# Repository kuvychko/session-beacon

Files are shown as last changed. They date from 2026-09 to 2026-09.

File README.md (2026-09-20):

# Session Beacon

A small USB-attached status light for Claude Code. It shows, at a glance, every Claude Code session running on the machine, which ones are waiting on you, and a few coarse usage numbers, on a 1.8" colour TFT sitting next to the monitor.

The problem it solves: with three or four VS Code windows each running Claude Code, it is easy to leave one session blocked on a permission prompt for twenty minutes without noticing. Desktop notifications get lost or dismissed. A dedicated physical display does not.

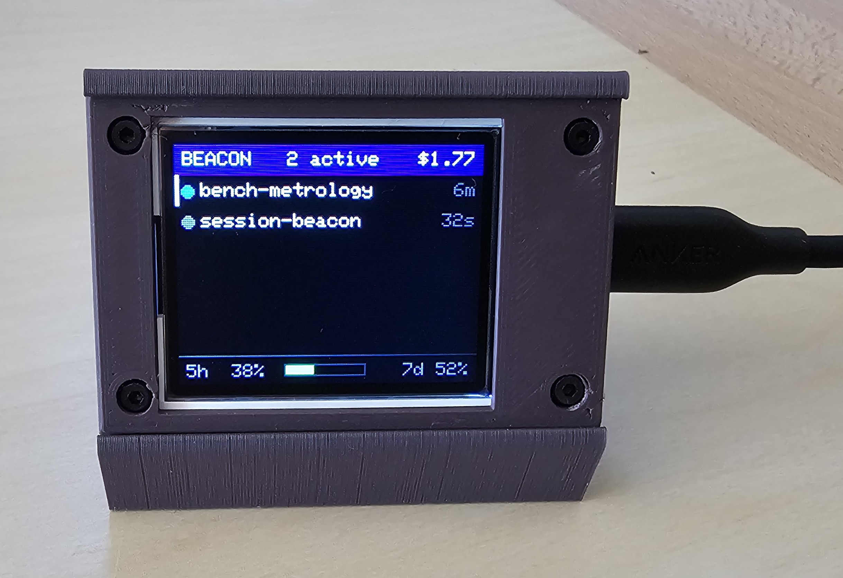
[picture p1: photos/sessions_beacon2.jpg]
The finished beacon


Two sessions on screen, in the 25-degree desk stand. `bench-metrology` last changed
state six minutes ago, `session-beacon` thirty-two seconds ago. The bar down the left
of the top row marks the session the footer is describing. The header totals spend
across every live session; the footer is caught on its usage page, showing 38% of the
rolling five-hour limit and 52% of the seven-day one.

---

## Hardware

| Part | Notes |
|---|---|
| Arduino Nano ESP32, **headerless** | ABX00092, not the headered ABX00083. ESP32-S3, native USB CDC, 3.3 V logic. The reference build, complete and in daily use |
| *or* Waveshare RP2040-Zero, **without headers** | The cheaper, smaller build, since Wi-Fi is never used. Runs the same firmware from the same source, on the same daemon |
| 1.8" TFT, 128x160, ST7735S | SPI, 3.3 V, 8-pin header, [this JESSINIE listing](https://www.amazon.com/dp/B0D31BGJWF). Both panels bought from it were BGR-wired and need a one-line colour-order fix, without which red and blue render swapped. Verify yours; the check is free. |
| USB-C cable | Data + power, nothing else needed |
| Enclosure, 3 printed parts | 40 x 60 mm, 19 mm deep. The middle and back parts come in a version for each board. SolidWorks, STEP and 3MF in [`enclosure/`](enclosure) |
| Desk stand, 1 printed part, optional | Tilts the screen back 25 degrees. The case is a friction fit in the slot, so nothing fastens it |
| 4x M2 x 16 socket-head screws + 4x M2 nuts | Head and nut both counter-sunk into the 19 mm stack. Length excludes the head, per the machine screw convention |
| 26 AWG silicone hookup wire, tinned copper | Eight conductors, soldered direct to the display's bent-over header. Silicone is required, not preferred: PVC is stiff enough to lift the board out of its retaining ridges |

Wiring needs no passives or level shifting: eight conductors, all 3.3 V. The Nano's
is carried over from the `env_monitoring` firmware. See
[docs/hardware.md](docs/hardware.md) for the pinout and bring-up procedure, and
[docs/enclosure.md](docs/enclosure.md) for the case and the full bill of materials.

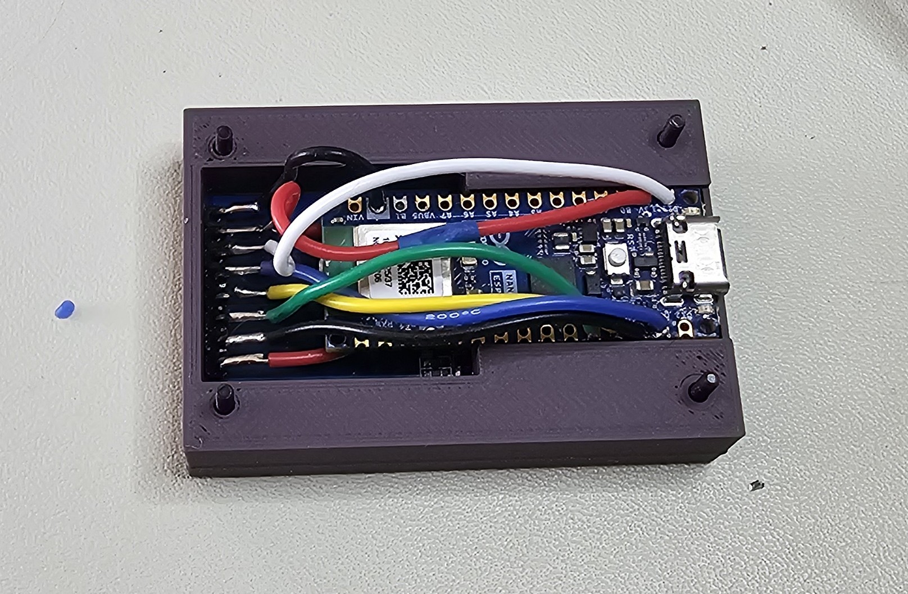
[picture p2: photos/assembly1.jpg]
Inside the case


The open case shows why three items in that list are requirements rather than
preferences. The Arduino is the headerless board, so its pads are bare and the printed
ridges can close directly onto the PCB to retain it. The display's eight-pin header is
bent flat against the board with wires soldered straight to it, because a socket would
not fit under the lid. And the wire is silicone: one jacket is printed `200 C`, which is
the rating that stops it shrinking back from the iron on leads this short.

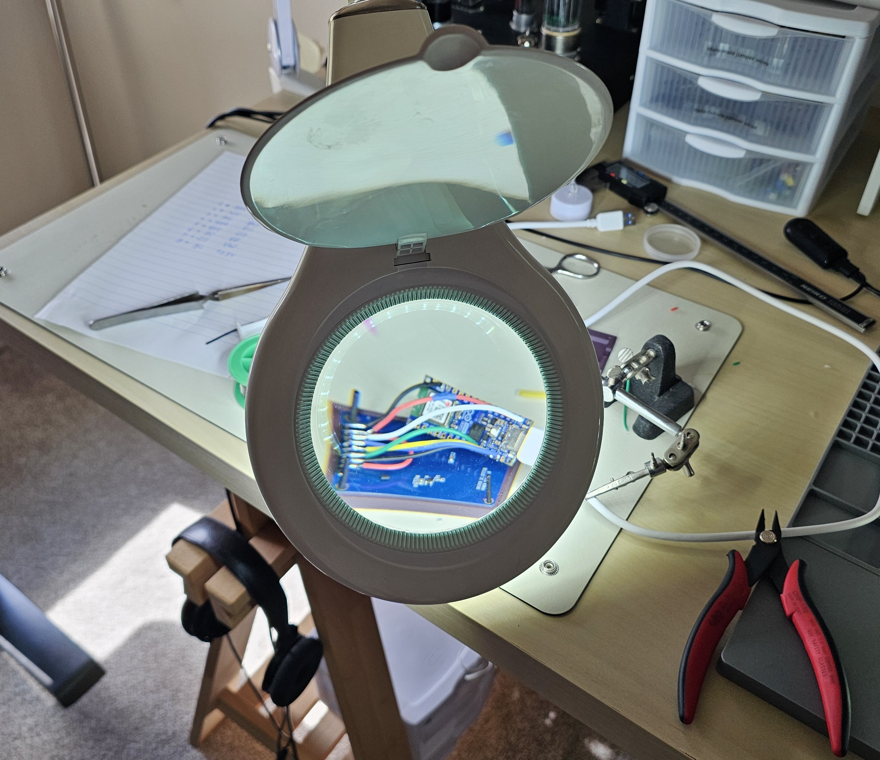
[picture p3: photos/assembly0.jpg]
Soldering under a magnifier


Soldering the bent header. Eight joints on 2.54 mm pitch, done under a magnifier lamp.

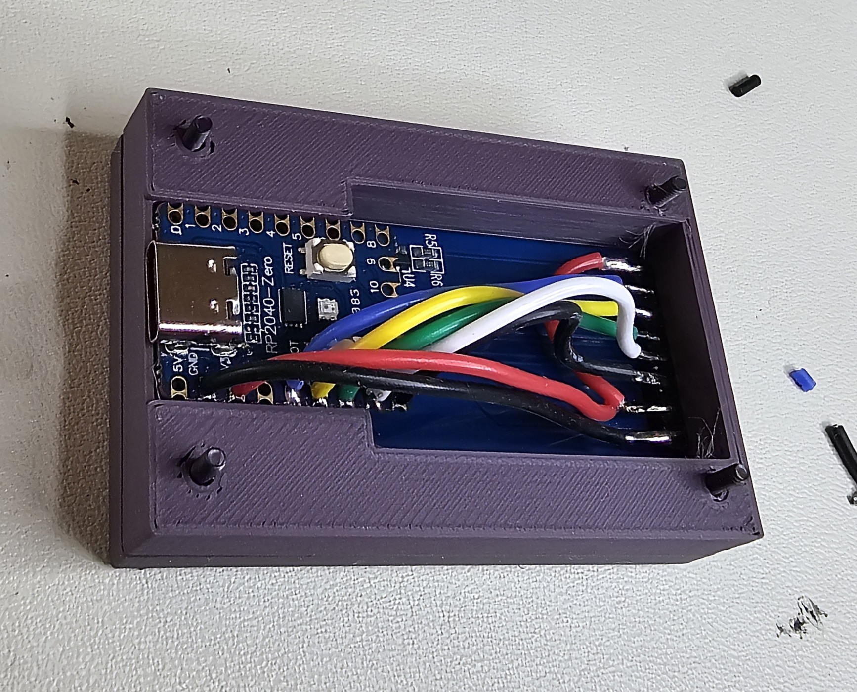
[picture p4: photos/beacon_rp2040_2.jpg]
The RP2040-Zero build, wired and seated in its case


The second build, on a Waveshare RP2040-Zero. Same display, same eight wires, same
firmware from the same source; a different mid and back part hold the smaller board.
Its parts laid out before assembly, and what differs between the two builds, are in
[docs/enclosure.md](docs/enclosure.md#two-builds).

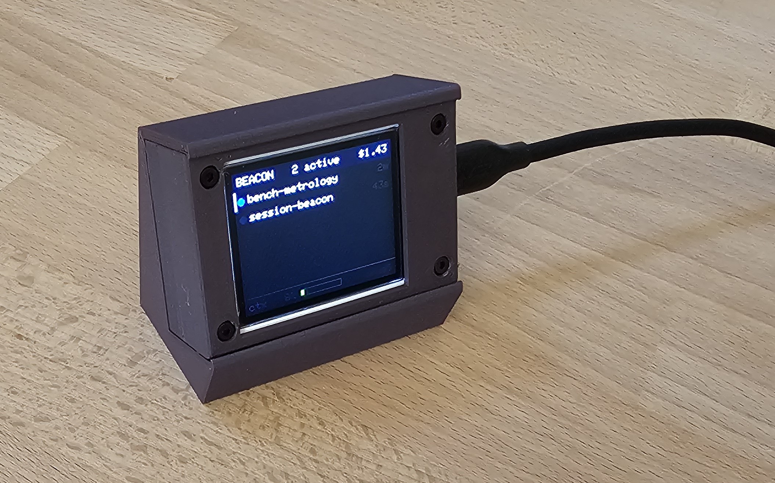
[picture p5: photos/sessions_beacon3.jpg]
The beacon in its stand, from the side


The stand seen from off-axis. Flat on the desk the screen points at the ceiling; 25
degrees back is what makes it readable from a seated position. The case is a friction
fit in the slot, so the stand is genuinely optional and nothing about the case depends
on it.

---

## How it works

```mermaid
flowchart LR
    subgraph pc["Windows PC"]
        cc1["Claude Code\n(VS Code #1)"]
        cc2["Claude Code\n(VS Code #2)"]
        cc3["Claude Code\n(terminal)"]
        hook["curl\n(one call per hook event)"]
        daemon["beacon-host\n(Python daemon)"]
        cc1 & cc2 & cc3 -->|"hooks + statusline"| hook
        hook -->|"HTTP POST\nlocalhost:47391"| daemon
    end
    subgraph dev["Nano ESP32"]
        fw["firmware"]
        tft["ST7735 TFT"]
        fw --> tft
    end
    daemon -->|"USB serial\nnewline JSON"| fw
```

1. **Claude Code hooks** fire on session lifecycle events. Each one is a single `curl` call to the daemon, which measured about eight times cheaper than starting a Python interpreter per event.
2. **beacon-host** keeps a per-session state machine (see [what the colours mean](#what-the-colours-mean)), decides how loudly each one should be shown, enriches it with cost and context data from the statusline hook, and pushes a compact snapshot to the device whenever anything changes.
3. **Firmware** is deliberately dumb: it parses the snapshot and draws it. All policy lives on the host so it can change without reflashing.

On the screen, one row per session:

```
+----------------------------------------+
| BEACON      6 active         $61.17    |
|----------------------------------------|
|############ env_monitoring     44s ####|  wants you now: filled red, pulsing
|############ data-pipeline       5m ####|  still waiting: filled red, static
| o session-beacon                 2m    |  blue: working
| o inventory..vice2               3m    |  cyan: idle, background work running
| o web-frontend                  15m    |  amber: busy but gone quiet
| o homelab                        7s    |  green: finished its turn
|----------------------------------------|
| ctx  73% [#######...]         opus5    |  <- 4s
| 5h   92% [#########.]      7d  28%     |  -> 4s
+----------------------------------------+
```

The bar down the far left of the top row marks the session the footer's context
page is describing. The footer alternates every four seconds between that session
and your account's rolling five-hour and seven-day usage.

State is carried by colour rather than a word, and the elapsed time is how long a
session has been in that state. The one that wants you fills its whole row and
pulses, which reads from across a desk in a way six-pixel text does not.

**The alarm decays.** It pulses for two minutes, then holds a static red for
another eight, then settles to an amber dot and sinks below the working sessions.
Leaving a session parked is a normal way to work, and a red light that never goes
out is one you stop reading. Both timings are config. See
[the attention ladder](docs/architecture.md#the-attention-ladder).

Labels longer than the 16 characters a row has room for lose their middle, not
their end, so `inventory-service2` shows as `inventory..vice2`. Two clones of one
repository usually differ only at the end of the name.

### What the colours mean

Every row is in one of these states. The diagram shows how a session moves
between them. All the timings are defaults and can be changed in
`host/config.toml`.

```mermaid
stateDiagram-v2
    direction LR
    state "STARTING: grey dot" as STARTING
    state "WORKING: blue dot" as WORKING
    state "IDLE: green dot" as IDLE
    state "NEEDS_LOOK: cyan dot and age" as NEEDS_LOOK
    state "STALE: amber dot and age" as STALE
    state "ERROR: magenta dot and age" as ERROR
    state "Waiting on you" as ASK {
        state "NEEDS_INPUT: red row, pulsing" as NEEDS_INPUT
        state "NEEDS_HELD: red row, steady" as NEEDS_HELD
        state "WAITING: amber dot and age" as WAITING
        [*] --> NEEDS_INPUT
        NEEDS_INPUT --> NEEDS_HELD: 2 min in
        NEEDS_HELD --> WAITING: 10 min in
    }

    [*] --> STARTING: session opens
    STARTING --> WORKING: you send a prompt
    IDLE --> WORKING: you send a prompt
    ERROR --> WORKING: you send a prompt
    WORKING --> IDLE: Claude finishes its turn
    WORKING --> ERROR: API error, e.g. a rate limit
    WORKING --> STALE: no activity for 5 min
    IDLE --> STALE: no word from Claude Code for 10 min
    STARTING --> STALE: same
    STALE --> WORKING: activity resumes
    WORKING --> ASK: permission prompt or question
    IDLE --> ASK: Claude has waited on you a while
    IDLE --> NEEDS_LOOK: same, but a workflow or background shell is still running
    NEEDS_LOOK --> WORKING: Claude picks up again
    NEEDS_LOOK --> ASK: still quiet 5 min later
    ASK --> WORKING: you answer

    classDef grey fill:#8c8c8c,stroke:#5c5c5c,color:#fff
    classDef blue fill:#009eff,stroke:#0070b8,color:#fff
    classDef green fill:#1db954,stroke:#12803a,color:#fff
    classDef cyan fill:#00e5e5,stroke:#009999,color:#003333
    classDef red fill:#e02020,stroke:#901010,color:#fff
    classDef amber fill:#ffa400,stroke:#b37300,color:#000
    classDef magenta fill:#ff00ff,stroke:#a000a0,color:#fff
    class STARTING grey
    class WORKING blue
    class IDLE green
    class NEEDS_LOOK cyan
    class NEEDS_INPUT,NEEDS_HELD red
    class WAITING,STALE amber
    class ERROR magenta
```

Any state goes to `ENDED`, a grey label, when the session closes, and the row is
dropped 30 seconds later.

| State | On the display | What it means | What to do |
|---|---|---|---|
| `STARTING` | grey dot | The session opened; no prompt yet | Nothing |
| `WORKING` | blue dot | Claude is thinking or using tools, or the turn has ended but a subagent it started is still running | Nothing |
| `IDLE` | green dot | Claude finished its turn and has nothing left running. Nothing has asked for you yet. This includes a turn that ends with a question in plain text | Send the next prompt when you're ready. It turns red once Claude Code reports the session has sat idle a while |
| `NEEDS_LOOK` | cyan dot, cyan age | Claude has gone quiet, but a workflow, background shell or similar is still running, so it is probably waiting on that and not on you | Glance at it when convenient. It turns red after 5 min |
| `NEEDS_INPUT` | whole row red, pulsing | Blocked on you. Red at once for a permission prompt or a question dialog; red later for a green row Claude Code has flagged as idle too long | Answer it |
| `NEEDS_HELD` | whole row red, steady | The same, 2 to 10 minutes in | Answer it |
| `WAITING` | amber dot, amber age | The same, over 10 minutes in. Sorted below working sessions | Answer it when you get back |
| `STALE` | amber dot, amber age | Nothing has been heard for longer than a live session stays quiet: 5 min while working, 10 min while green or grey. Usually a window closed without ending the session | Check the window |
| `ERROR` | magenta dot, magenta age | The turn ended on an API error such as a rate limit | Retry when you can |
| `ENDED` | grey label | The session closed | Nothing; the row disappears |

Green and red both mean Claude is waiting on you. The difference is whether
anything has said so. A finished turn (`Stop`) is green, because it is not
urgent yet. A row turns red when Claude Code says it is blocked: straight away
for a permission prompt or a dialog, or later through its `idle_prompt`
notification once a green row has gone unanswered. The beacon keeps no idle
timer of its own for red. It turns red only when Claude Code sends that
notification.

It does notice when that notification never comes. A live session sends it a
few minutes into the wait, so a green row that has heard nothing at all for 10
minutes is almost certainly a window closed without ending its session, and it
turns amber `STALE` instead of staying green for a day. A live parked session
would have reached amber by then anyway, through the red rungs.

Rows are sorted so the most urgent come first: the red rows, then `ERROR`,
`NEEDS_LOOK`, `WORKING`, `WAITING`, `STALE`, `STARTING`, `IDLE`. The age on each
row is how long the session has been in its current state. Across the red and
amber rungs it keeps counting, so it shows how long the session has been waiting
on you. It restarts when a cyan row turns red.
[docs/architecture.md](docs/architecture.md#session-state-machine) has the same
machine in terms of Claude Code hook events.

The beacon also reports itself in the terminal, through the same status line that
feeds it the cost and context figures:

The beacon marker in the Claude Code status line

The trailing `beacon` is the daemon confirming it is talking to the device. It
turns into `beacon?` when it is not, which is how an unplugged display or a
half-dead daemon announces itself without your having to look away from the
terminal. `beacon silent` means the board is plugged in but has stopped
answering. That is worth a glance at the beacon rather than a replug: the daemon
cannot see whether the display froze with it or is still drawing perfectly behind
a dead return path, and the board reboots itself out of either within a minute.
Everything to its left comes from the same payload the device gets.

Details: [docs/architecture.md](docs/architecture.md), [docs/protocol.md](docs/protocol.md), [docs/claude-code-integration.md](docs/claude-code-integration.md).

---

## Status

**Working end to end on Windows.** Hooks feed the daemon, the daemon drives the
display, and the whole path has been exercised on real hardware.

Verified on the bench: wiring and panel colour order, firmware rendering and its
timers, the daemon and its state machine, hook delivery from live sessions,
session labelling, hardware SPI at 24 MHz, session state surviving a daemon
restart, and the attention state from a captured `idle_prompt`.

**The attention path is evidence, not reasoning.** It was the one part of the
display resting on inference: the events that turn a row red had never been seen
firing. Both are now captured and committed as fixtures — a `Notification`
carrying `notification_type: "idle_prompt"`, and the dedicated
`PermissionRequest` — so the red row is covered by replayed payloads rather than
hand-written ones. The `idle_prompt` arrived *twice* for the same unanswered
session, which is why the alarm arms only when a session first starts waiting.

**One surprise.** Refusing a permission prompt did not produce a
`PermissionDenied`, though the hook was registered and the matching
`PermissionRequest` arrived. The CLI turns out to reserve that event for denials
made by the auto-mode classifier, not by a person, and a refused call runs no
tool so there is no `PostToolUse` either. Answering a prompt with feedback
therefore left the row red until Claude's next tool call. `PostToolBatch` — which
fires once a batch resolves, refusals included — is what closes that gap.

The enclosure is printed and fitted, so it is a finished object rather than a
breadboard. Remaining work is comfort rather than function: see
[docs/roadmap.md](docs/roadmap.md).

---

## Contributing and licence

Three licences, one per kind of work, all permissive. Full texts in
[`LICENSES/`](LICENSES), and [LICENSE](LICENSE) maps them to paths.

| What | Licence |
|---|---|
| Software and firmware | MIT |
| Enclosure design files | CERN-OHL-P-2.0 |
| Documentation and photos | CC BY 4.0 |

Code samples inside the documentation are MIT, not CC BY, so you can copy a pin
definition or a shell command without attributing anything. Every dependency is
BSD or MIT, so nothing here constrains what you do with it.

**There are two builds.** The Nano ESP32 is overkill for this: its Wi-Fi and Bluetooth
are most of what you pay for and the project uses neither, by design. A Waveshare
RP2040-Zero is cheaper and smaller, and runs the same firmware, built from the same
source, talking to the same daemon
([what the port involved](docs/roadmap.md#the-rp2040-zero-edition)). How the two differ is in
[docs/enclosure.md](docs/enclosure.md#two-builds). The case is published as STEP as
well as mesh, so adapting it to another board does not depend on owning SolidWorks.

## Repository layout

```
firmware/beacon/          Arduino sketch, one source for both boards (Adafruit_ST7735)
firmware/tft_smoketest/   Standalone wiring/display test, flash this first
host/                     Python daemon: hook receiver, state, serial link
  src/beacon_host/
hooks/                    Example Claude Code settings, plus a payload capture tool
scripts/                  install-hooks.ps1, install-task.ps1, restart-daemon.ps1, uninstall.ps1
enclosure/                Three printed parts plus an optional stand: SolidWorks source, STEP, and 3MF
photos/                   Build and finished-device photos, and UI screenshots
docs/                     Architecture, hardware, enclosure, protocol, integration, roadmap
```

---

## Quick start

Every path below is relative to the **repository root**. The daemon runs in the
foreground and never exits on its own, so it needs a terminal of its own.

### 1. Build the device

Wire the display per [docs/hardware.md](docs/hardware.md), then flash
`firmware/tft_smoketest` and work through the bring-up checks before going near
the real firmware. When the colours and geometry look right:

```powershell
$cli = "$env:LOCALAPPDATA\Programs\Arduino IDE\resources\app\lib\backend\resources\arduino-cli.exe"
& $cli compile --fqbn arduino:esp32:nano_nora firmware/beacon
& $cli upload  --fqbn arduino:esp32:nano_nora -p COM4 firmware/beacon
& $cli board list    # if COM4 is wrong
```

The display should now read `no host`, which is correct: nothing is talking to
it yet.

### 2. Install the host software

```powershell
cd host
uv sync
uv run pytest                        # no hardware needed
uv run beacon-host --dry-run -v      # prints snapshots, Ctrl-C to stop
cd ..
```

`--dry-run` still binds the HTTP port, and the daemon refuses to share it, so
this exits with `cannot bind 127.0.0.1:47391` if one is already running. That is
deliberate: two daemons on one port would split the hook events between them at
random and neither would show the whole picture. If you have already reached
step 5, stop the scheduled task first and start it again afterwards:

```powershell
./scripts/restart-daemon.ps1 -StopOnly    # from the repository root
# ... run the daemon in the foreground ...
./scripts/restart-daemon.ps1
```

Use that script for every restart, and never start the daemon with
`Start-Process`: the Scheduled Task cannot stop a daemon it did not launch, so
the next restart through the task quietly fails. The script stops every
beacon-host process however it was started, and fails unless a fresh daemon
answers `/health`. Stop it the same way before flashing firmware, because the
daemon holds the COM port.

### 3. Terminal 1: start the daemon and leave it running

```powershell
cd host
uv run beacon-host                   # finds the board by USB id; blocks until Ctrl-C
```

The display should switch from `no host` to `no sessions`. That is the daemon
talking to the device with nothing yet to report.

**Leave this running.** Everything below happens in a second terminal.

### 4. Terminal 2: install the hooks

```powershell
cd C:\path\to\session-beacon        # repository root, not host/
./scripts/install-hooks.ps1 -WithStatusLine
```

Omit `-WithStatusLine` to keep a status line you already have, at the cost of
the cost and context figures, which arrive only through that hook.

**Now restart your Claude Code sessions.** Hooks are read when a session starts,
so nothing reaches the daemon until you do. This is the step people miss.

```powershell
curl.exe -s http://127.0.0.1:47391/health
```

`events_received` should climb as you use Claude Code, and the display should
show a row per session.

### 5. Optional: survive a reboot

The daemon in Terminal 1 dies when you close that window. To have it start at
logon instead, with no console:

```powershell
./scripts/install-task.ps1           # from the repository root
./scripts/restart-daemon.ps1         # starts it now, and confirms it answers
```

To undo all of it, including the hooks, the scheduled task, the running daemon
and the logs:

```powershell
./scripts/uninstall.ps1 -WhatIf    # show what it would touch
./scripts/uninstall.ps1
```

Setup reaches outside this repository, so deleting the folder would leave a
Scheduled Task, hooks in your Claude Code settings and a daemon holding a COM
port behind. The uninstall script keeps anything it did not create: your own
hooks, your other settings, your config file, and a status line it replaced is
restored rather than dropped.

If the display says `no sessions`, the daemon and the wiring are fine and
Claude Code simply is not calling the hooks. Check `events_received` at
`/health`, then re-run `install-hooks.ps1` and restart your sessions.

If the display shows *fewer* sessions than you have open, that is a different
fault and the hooks are not the cause. A session sitting on a prompt sends no
events, so it is only known to the daemon from its saved state; check the `rows`
field at `/health` against what is on screen. Some sessions are dropped on
purpose: any session with no activity for `restore_max_age_s` (24 h), and, after
the PC restarts, every session from before the restart, because none of them
can have survived it.

If the display shows a session you closed long ago, typically an amber row with
an age in days, its window was killed without telling Claude Code to end the
session. A Windows Update restart does this. The row goes by itself once it has
been silent for 24 hours, and restarting the scheduled task clears it at once
if the PC has rebooted since.

If the footer says `no statusline data`, everything else is working but the
statusline hook is not installed. That hook is the only source of cost and
context figures. Re-run `install-hooks.ps1 -WithStatusLine` and restart your
sessions. If you already had a status line of your own, the installer saves it
and `uninstall.ps1` puts it back.

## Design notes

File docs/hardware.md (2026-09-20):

# Hardware

There are two builds of the beacon. They share the display, the protocol, the daemon and
most of the enclosure, and differ only in the board and the parts of the case that hold
it. This file keeps the shared material once and gives each board its own section where
they differ.

| Build | Board | Status |
|---|---|---|
| Nano ESP32 | Arduino Nano ESP32, headerless | Complete, in daily use. The reference build |
| RP2040-Zero | Waveshare RP2040-Zero | Complete. Runs the same firmware from the same source, on the same daemon. See [the port's notes](roadmap.md#the-rp2040-zero-edition) |

## Parts

Shared:

- **1.8" TFT LCD, 128x160, ST7735S, 3.3 V, SPI, 8-pin.** [JESSINIE module](https://www.amazon.com/dp/B0D31BGJWF) (ASIN B0D31BGJWF), the same listing used in `env_monitoring`. Same part number, but not an identical panel: see [Panel colour order](#panel-colour-order).

One of:

- **Arduino Nano ESP32, headerless** (ABX00092). ESP32-S3, USB-C, native USB CDC. Arduino pin names (`D10`, not GPIO numbers) are used throughout. The headered SKU is ABX00083 and will not fit the enclosure; see [enclosure.md](enclosure.md#assembly-constraints).
- **Waveshare RP2040-Zero**, the plain one, without headers soldered on. RP2040, USB-C, 3.3 V logic. The RP2040-Zero-M has headers pre-soldered and will not fit the enclosure.

Power: everything runs off the board's 3.3 V pin from USB. The display draws about 30 mA including backlight, so either board's onboard regulator handles it comfortably.

## Wiring

Eight wires, no passives, no level shifting. Both boards are 3.3 V logic, like the display. The display's two power pins and six signals are the same for both builds; only the board end differs.

Order the display's header as printed on its own silkscreen. On this module it reads `GND VCC SCL SDA RES DC CS BLK` from one end, but check yours rather than counting positions.

In the enclosed build the wires are 26 AWG silicone, soldered directly to the display's bent header and to the board. See [enclosure.md](enclosure.md#assembly-constraints) for why silicone is required.

### Nano ESP32

Identical to `env_monitoring`, which is known to work with this exact display. That table is the authority; this one is copied from it.

| Display pin | Nano ESP32 pin | Notes |
|---|---|---|
| VCC | 3V3 | **3.3 V only. 5 V will damage the module.** |
| GND | GND | |
| CS | D10 | Chip select |
| RST (RES) | D9 | Reset |
| DC (A0) | D8 | Data / command |
| SDA (MOSI) | D11 | SPI data |
| SCL (SCK) | D13 | SPI clock |
| BLK (LED) | 3V3 | Backlight, always on |

#### Finding the pins on the Nano

Every pin is labelled on the Nano's silkscreen, so trust the board over any diagram. Two things make this wiring easy:

- **D8, D9, D10, D11 are four consecutive pins** on one header, in that order. Four of the six signal wires go to one contiguous run.
- **D13 and 3V3 are both on the opposite header**, near the USB end.

A GND pin is available on both headers; use whichever is closer to your display. The display's 8 pins are in one row on a 2.54 mm header, so female-to-female jumpers work directly, or male-to-female into a breadboard.

### RP2040-Zero

All eight wires go to one edge of the board: the left edge, looking at the component side with the USB-C connector at the top. That is the edge that faces the display's header in `mid-rp2040`.

| Display pin | RP2040-Zero pin | Notes |
|---|---|---|
| GND | `GND` | Second pad from the top |
| VCC | `3.3V` | **3.3 V only. `5V` is the pad above `GND`, two above this one.** |
| BLK (LED) | `3.3V` | Backlight, always on. A second wire into the `3.3V` pad, or a short link to VCC at the display header |
| — | `29` | Spare |
| CS | `28` | Chip select |
| DC (A0) | `27` | Data / command |
| RST (RES) | `26` | Reset |
| SDA (MOSI) | `15` | SPI data: SPI1 TX |
| SCL (SCK) | `14` | SPI clock: SPI1 SCK |

#### Finding the pins on the RP2040-Zero

**Go by the labels printed on the board, never by position numbers.** The three power pads are printed `5V`, `GND` and `3.3V`; every other pad is printed with its bare GPIO number. Pinout diagrams, including the one in the Arduino core, number the pads by header position from 1 at `5V`, and those numbers collide with the printed ones: the pad printed `1` is GPIO 1, in the top-right corner, nowhere near the top-left `5V`. Only the printed labels are used here.

Looking at the component side with the USB-C connector at the top, the left edge reads from top to bottom:

```
5V  GND  3.3V  29  28  27  26  15  14
```

The labels then carry on counter-clockwise, across the bottom edge and up the right one.

Why these pins:

- **`14` and `15` are SPI1's clock and data**, and the Arduino core's defaults for SPI1. Hardware SPI needs no pin overrides.
- **Nothing the display uses clashes with SPI1's other defaults.** Its MISO (`12`) and SS (`13`) are on the bottom edge and stay unconnected. The firmware drives CS itself.
- **The wires never cross.** The display's `SCL SDA RES DC CS` run matches `14 15 26 27 28` going up the edge, so the five signal wires lie side by side.
- **`29` is left spare**, and so is GPIO 16, which drives the on-board RGB LED.

The firmware consequence: the display is on **SPI1**, not the default `SPI`, so the RP2040 firmware needs the constructor that takes a bus, `Adafruit_ST7735(&SPI1, TFT_CS, TFT_DC, TFT_RST)`. The three-argument one in [Display init](#display-init) would drive SPI0's pins, which are not wired.

### Before powering on

1. **VCC is on the 3.3 V pin**: `3V3` on the Nano, `3.3V` on the RP2040-Zero. Never VIN, VBUS or `5V`. This is the only mistake that destroys the display, and on the RP2040-Zero `5V` is two pads above the right one.
2. No wire is shorting to a neighbour where it meets the header or pad.
3. SDA goes to MOSI and SCL to SCK: D11 and D13 on the Nano, `15` and `14` on the RP2040-Zero. Swapping them gives a blank screen, not damage.

## Display init

Shown for the Nano ESP32, which is what `beacon.ino` builds for today. The init sequence, SPI clock, init tab and colour-order fix belong to the panel and carry over unchanged; the RP2040-Zero differs only in its pin numbers and in the constructor, which must name `&SPI1` (see [its wiring](#rp2040-zero)).

```cpp
#define TFT_CS    D10
#define TFT_RST   D9
#define TFT_DC    D8
#define TFT_MOSI  D11
#define TFT_SCLK  D13
static constexpr uint32_t SPI_HZ = 24000000;
Adafruit_ST7735 tft = Adafruit_ST7735(TFT_CS, TFT_DC, TFT_RST);   // hardware SPI

tft.setSPISpeed(SPI_HZ);     // 24 MHz
tft.initR(INITR_GREENTAB);   // required for the ST7735S variant
tft.setRotation(1);          // landscape, 160 wide x 128 high
applyPanelColorOrder();      // this panel is BGR-wired, see below
```

`TFT_MOSI` and `TFT_SCLK` are still defined because the bit-banging revert needs
them, but the 3-argument constructor above does not take them: naming them is
the library's signal to bit-bang. See below.

`INITR_GREENTAB` is not a guess to tune. `env_monitoring` established that this panel is an ST7735**S**, and the ST7735 (`BLACKTAB`) and ST7735R (`REDTAB`) gamma and offset tables produce shifted images or wrong colours on it. Bench testing confirmed the offsets and rotation are correct with `GREENTAB`.

### Hardware SPI

The firmware uses **hardware SPI**, selected by the 3-argument constructor. The
5-argument form names MOSI and SCK explicitly, which is the library's signal to
bit-bang those pins instead. `USE_HARDWARE_SPI` in `beacon.ino` switches between
them and is the whole revert.

On the Nano no rewiring was needed. The variant header for that board defines `MOSI` as `D11`
and `SCK` as `D13`, exactly where the display was already wired, so the sketch had
been bit-banging pins that can clock themselves.

Measured on the Nano ESP32, same scenes before and after:

| Case | Software SPI | Hardware SPI at 24 MHz |
|---|---|---|
| One row's elapsed time ticking | 28 ms | about 2 ms |
| Five rows plus a moving footer bar | ~140 ms extrapolated | 11 ms |
| Full-screen repaint | 900 ms | 140 ms |

Verified on hardware: the picture is clean at 24 MHz, with no speckling or
tearing, colours correct, the attention row pulsing and the footer bar sliding
smoothly. Timings and receive counters cannot show any of that, so this needed a
human looking at the panel.

The RP2040-Zero build drives the same panel at the same 24 MHz over SPI1, and its heartbeats report 0 to 1 ms for the small repaints that a snapshot with one changed field causes, against about 2 ms on the Nano. Its full-screen repaint has not been measured separately; there is no reason to expect it to differ much, since the panel and the clock are the same.

The clock is set to 24 MHz rather than the library's 32 MHz default. An ST7735S on
jumper wires is not guaranteed at 32 MHz, and the failure is cosmetic and confusing
rather than clean: speckled pixels or a torn frame, not a blank screen. Lower
`SPI_HZ` first if the picture is ever dirty.

### Panel colour order

**This panel is BGR-wired.** With the library's defaults it renders red and blue swapped.

An earlier version of this file said `env_monitoring`'s display did not need the same fix, and called colour order a per-unit trait. That was inferred from a code comment reading "Dark blue", never from looking at the screen, and it was wrong: that panel is BGR too and had been showing high CO2 readings in blue instead of red the whole time. Both panels from this listing have been BGR, so expect BGR.

Still check a new panel rather than assuming, because the check is free: fill the screen with `0x000F` and see whether it comes out blue or red. Getting it wrong costs a warning colour that reads as a calm one.

The Adafruit library exposes no API for this, so the fix is a direct write to the Memory Access Control register with the colour-order bit cleared:

```cpp
static constexpr uint8_t CMD_MADCTL  = 0x36;
static constexpr uint8_t MADCTL_MY   = 0x80;
static constexpr uint8_t MADCTL_MV   = 0x20;
static constexpr uint8_t MADCTL_BGR  = 0x08;  // clear this bit for RGB order

// What the library writes for INITR_GREENTAB at rotation 1, minus the BGR bit.
static constexpr uint8_t MADCTL_ROT1_RGB = MADCTL_MY | MADCTL_MV;

static void applyPanelColorOrder() {
  uint8_t v = MADCTL_ROT1_RGB;
  tft.sendCommand(CMD_MADCTL, &v, 1);
}
```

`setRotation()` rewrites this register, so the override has to come after it. There is only one `setRotation()` call in the firmware; any new one needs `applyPanelColorOrder()` after it. With the override in place every `ST77XX_*` constant and every raw hex colour behaves as documented, so no other code has to know about this.

## Arduino IDE setup

Both builds use the same libraries, via Library Manager: `Adafruit GFX Library`, `Adafruit ST7735 and ST7789 Library`, and `ArduinoJson` (v7, needed by `beacon.ino` but not by the smoke test). All three support both microcontrollers.

### Nano ESP32

- Board package: **Arduino ESP32 Boards** (Arduino's own fork), board **Arduino Nano ESP32**.
- Upload over USB. The board enumerates as a COM port; during flashing it re-enumerates, so the host daemon must tolerate the port disappearing and coming back.

### RP2040-Zero

- Board package: **[arduino-pico](https://github.com/earlephilhower/arduino-pico)** (`rp2040:rp2040`), board **Waveshare RP2040 Zero**, FQBN `rp2040:rp2040:waveshare_rp2040_zero`. Add `https://github.com/earlephilhower/arduino-pico/releases/download/global/package_rp2040_index.json` to the board manager URLs.
- Upload over USB. `arduino-cli upload -p COMx` reboots the board into its bootloader with a 1200-baud open, then copies the `.uf2`. If the board is already in BOOTSEL, or the upload cannot find the port, copy `beacon.ino.uf2` onto the `RPI-RP2` drive by hand; that is all the upload does.
- Hold BOOT while plugging the board in to force BOOTSEL. A board with no firmware on it comes up that way already.

## Bring-up procedure

Flash `firmware/tft_smoketest/tft_smoketest.ino` before `beacon.ino`. It is written for the Nano ESP32; the RP2040-Zero needs the same pin and constructor changes as the beacon before it can run there. It needs no host software and no ArduinoJson, so it isolates wiring problems from everything else. Open the Serial Monitor at 115200 with the Newline line ending.

It applies this unit's colour-order correction at init, runs a self-test, then accepts single-letter commands so you can re-run any step or change the colour order without reflashing.

| Command | Does |
|---|---|
| `c` | Colour chart, the diagnostic for swapped channels |
| `r` | Per-channel ramps |
| `g` | Geometry, border and corner markers |
| `t` | Text metrics |
| `l` | Mock of the real beacon layout |
| `a` | Whole self-test again |
| `n` | Revert to the library's colour-order value, which is wrong on this unit |
| `x` | Toggle the RGB/BGR colour-order bit |
| `mA0` | Set the colour-order register to a raw hex value |

What each step proves:

| Step | What you should see | What a failure means |
|---|---|---|
| Geometry | A white border touching all four edges, corners reading TL, TR, BL, BR clockwise from top left | A coloured band along an edge, or a cut-off row, means a wrong panel offset and so a wrong init tab. Corners out of order means a wrong rotation. |
| Text | 26 characters across one line at size 1 | Confirms the font metrics the beacon layout assumes. |
| Colour chart | Six labelled bars reading red, green, blue, cyan, magenta, yellow | Anything else is a channel permutation. See below. |
| Layout | A mock of the real beacon screen | The layout review. Judge row pitch and colours here, not after writing host software. |

If the screen stays dark through all of it but the Serial Monitor prints the banner, the board is fine and the problem is in the eight wires. If the Serial Monitor prints nothing, it is the board, the cable, or the port selection.

## Colour channel troubleshooting

Resolved for the current unit, but keep this for the next panel.

The `c` command in the smoke test draws six patches chosen so that every channel permutation produces a different-looking screen. Read the bars top to bottom and find the column that matches.

| Bar | Sent | Correct | R and B swapped | R and G swapped | G and B swapped |
|-----|---|---|---|---|---|
| R | `F800` | red | blue | green | red |
| G | `07E0` | green | green | red | blue |
| B | `001F` | blue | red | blue | green |
| C | `07FF` | cyan | yellow | magenta | cyan |
| M | `F81F` | magenta | magenta | cyan | yellow |
| Y | `FFE0` | yellow | cyan | yellow | magenta |

Pure red, green, and blue alone cannot distinguish these cases. The cyan, magenta, and yellow bars are what disambiguate.

Red and blue swapped is the panel colour-order flag and is fixed in the register, as described above. Both sketches now boot with the correction applied; `n` reverts to the library value to show the fault again, and `x` toggles.

The other two permutations cannot come from that flag. Red and green also occupy different bit widths in the pixel format, five bits against six, so a genuine swap of those two is not something the controller offers. If a future panel lands in one of those columns, correct the palette constants in software instead of hunting for an init sequence. That costs nothing at runtime because the beacon defines every colour in one block at the top of `beacon.ino`.

## USB serial notes

The daemon is the same program for both builds and speaks the same [protocol](protocol.md) to either. Detecting which port the board is on is the only part of it that depends on the board, and the heartbeat's `board` field says which build answered.

### Nano ESP32

- The Nano ESP32 uses the ESP32-S3's native USB, so `Serial` is USB CDC. The baud rate is nominal; 115200 is used by convention.
- USB CDC takes a moment to enumerate after reset, so the smoke test waits 1.5 s before its first print. Without that delay the banner is often lost.
- Opening the port from the host may or may not reset the board depending on DTR handling. Firmware must not depend on a reset at connect. It renders whatever arrives.
- Windows assigns a COM number per physical USB port, and it can change if the cable moves. The host daemon auto-detects by VID/PID (`0x2341:0x0070`) as a fallback to the configured port.

### RP2040-Zero

- `Serial` is USB CDC through TinyUSB, as on the Nano, but a different implementation, so the Nano's findings were re-checked rather than assumed.
- **`write()` gives up after one second** instead of blocking forever. That is the fault that froze the Nano eight times in eight days, and it cannot hang this board outright. A second is still most of a frame, so both builds queue their output and pump it; see `txLine()`/`txPump()`.
- **`Serial` as a boolean is `tud_cdc_connected()`**, the same predicate the Nano build spells out by hand, and the same one this core's `write()` and `availableForWrite()` consult. The Nano's warning against `if (Serial)` is about the ESP32 core's separate flag and does not apply here.
- **There is no `setRxBufferSize()`.** The CDC receive buffer is whatever the core compiled in. Nothing is lost when it fills: USB CDC applies back-pressure, so the host's write waits instead.
- **Opening the port at 1200 baud reboots the board into its bootloader.** That is how `arduino-cli` flashes it. The daemon opens at 115200 and never changes the baud rate, so it cannot trip this; it is the RP2040's equivalent of the DTR/RTS pattern the Nano watches for, and the same rule follows: nothing on the host may try to revive a board by fiddling with the port.
- The board enumerates as VID/PID `0x2E8A:0x0003`, the Raspberry Pi vendor and the generic RP2040 product id. Every RP2040 board shares it, so the daemon's auto-detect recognises "an RP2040", not specifically a Zero. Use `--port COMx` if another RP2040 device is plugged in.
- Windows assigns a COM number per physical USB port here too.

## Enclosure

Done for both builds, unlike `env_monitoring`, which never got past the breadboard. Three printed parts stacking to 19 mm on a 40 x 60 mm footprint, with a middle and back part cut for each board, held by four M2 x 16 socket-head screws, plus an optional stand that tilts the whole thing back 25 degrees. Source files and the full bill of materials are in [enclosure.md](enclosure.md).

One thing it changes about the wiring above: the enclosed build uses 26 AWG **silicone**-insulated stranded wire rather than the breadboard jumpers used for bring-up. Silicone has almost no memory, so it lies where it is put; PVC jumpers spring back hard enough to push the display off its seat and stop the case closing.

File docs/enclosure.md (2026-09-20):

# Enclosure

Three printed parts that sandwich the board and display, held together by four screws
through the stack, plus an optional stand that tilts the finished case back 25 degrees.
Everything is in [`enclosure/`](../enclosure).

There are two builds, one per board (see [hardware.md](hardware.md)). They share the
front, the stand, the fasteners and the outside dimensions. Only the mid and back
parts, which hold the board, are cut for one board or the other.

| Part | Nano ESP32 build | RP2040-Zero build | Footprint | Depth |
|---|---|---|---|---|
| Front | `front-v0` | `front-v0` | 40 x 60 mm | 5.0 mm |
| Mid | `mid-v0` | `mid-rp2040-v0` | 40 x 60 mm | 8.0 mm |
| Back | `back-v0` | `back-rp2040-v0` | 40 x 60 mm | 6.0 mm and 9.0 mm |
| 25-degree stand (optional) | `25-degree-stand-v0` | `25-degree-stand-v0` | 38 x 60 mm | 51 mm tall |

Both cases have the same 40 x 60 x 19 mm envelope and take the same screws. The depths
are bounding boxes, and `back-rp2040-v0`'s 9 mm includes ridges that interlock into the
mid part when assembled, so the parts' depths do not add up to the stack.

### Which file to open

Each part ships in three formats. They are not redundant; they serve different jobs.

| Format | What it is | Reach for it to |
|---|---|---|
| `.SLDPRT` | SolidWorks 2026 source, with the feature history intact | Edit the design the way it was designed. Needs SolidWorks |
| `.STEP` | Neutral solid geometry, AP214 | Open and modify anywhere: FreeCAD, Fusion, Onshape, Blender. No feature history, so it arrives as a dumb solid |
| `.3MF` | Mesh | Slice and print. This is the one to hand your slicer |

**Print from the 3MF. Modify from the STEP unless you own SolidWorks.** The STEP is
the format that makes this project actually forkable: a dumb solid is still real
geometry you can cut, extend and re-export, which a mesh is not. If you are adapting
the case for a different board, that is where to start.

Stacked depth is 19 mm for either build. The footprint is smaller than the bare display module, which is
56 mm on its long edge, because the panel overhangs its own PCB.

Dimensions above were measured from the mesh bounding boxes in the 3MF files, so they
are the modelled sizes rather than the printed ones. Expect the usual shrinkage and
elephant's foot on the first layer.

## Bill of materials

| Qty | Item | Notes |
|-----|---|---|
| 1 | Arduino Nano ESP32, **headerless** | Nano build. **ABX00092**, not ABX00083. See below |
| 1 | Waveshare RP2040-Zero, **without headers** | RP2040 build, instead of the Nano. The plain one, not the pre-soldered RP2040-Zero-M. See below |
| 1 | 1.8" TFT, 128x160, ST7735S, 3.3 V, SPI, 8-pin | [JESSINIE listing](https://www.amazon.com/dp/B0D31BGJWF). Expect BGR wiring; see [hardware.md](hardware.md#panel-colour-order) |
| 4 | M2 x 16 socket-head cap screws | Counter-sunk into the stack; see below on length |
| 4 | M2 nuts | |
| 1 | USB-C cable, data and power | Nothing else connects to the outside |
| 8 | 26 AWG **silicone**-insulated hookup wire, stranded tinned copper | Board to display. Sold as "Flexible 26 Gauge Silicone Hook up Wire Kit, Electrical Tinned Copper Wire" |
| 3 | Printed parts | `front-v0`, plus `mid-v0` and `back-v0` for the Nano or `mid-rp2040-v0` and `back-rp2040-v0` for the RP2040-Zero |
| 1 | Printed stand, optional | `25-degree-stand` from `enclosure/`. Nothing fastens it; see below |

## Assembly constraints

Inside the case

The case is tight, and four things follow from that. None of them are preferences.
Everything below is visible in the photo above, which is the Nano build, and applies
to the RP2040-Zero build as well.

**Screw length is quoted under the head.** M2 x 16 means 16 mm of shank; the socket
head adds roughly 2.5 mm on top, for about 18.5 mm overall. Both the head and the nut
are counter-sunk into their parts, so the whole fastener disappears inside the 19 mm
stack with about half a millimetre to spare and nothing protrudes from either face.

Do not size the screw to the 19 mm stack. That convention is the trap: a 19 or 20 mm
screw is too long, not flush.

Socket head rather than hex head, so a driver reaches down into the counterbore
instead of needing side clearance for a wrench.

**The board must have no headers.** For the Nano that means ABX00092, not ABX00083,
which is the same board with pin headers already soldered on. The two are otherwise
identical, so it is an easy thing to order wrong. For the RP2040-Zero it means the plain
board with its loose header strips left in the bag, not the RP2040-Zero-M, which comes
with them soldered. Headers add height the case does not have, and more importantly the
clamshell ridges close onto the bare PCB to retain the board. There is nowhere for a
header strip to go. Wires are soldered straight to the board's pads.

**The display's 8-pin header is bent through 90 degrees** so the panel sits flat against
the front while the connections run back into the cavity. Wires are soldered directly to
those pins. No sockets, no dupont housings; both would add height and neither would
survive the bend.

**Nothing mechanically fastens the boards.** The clamshell ridges hold the Nano or the RP2040-Zero, and
the stack holds itself together through the four screws. That works because everything
inside is thin and nothing pushes back, which is the whole reason the wire specification
matters.

**The wire specification is not incidental, and silicone is the part that matters.**
Bring-up used ordinary breadboard jumper wires. They are PVC-insulated and stiff, they
hold whatever bend you last put in them, and inside a 19 mm cavity that spring-back
pushes the display off its seat and strains the header pins. The lid will not close.

Silicone-insulated wire solves it on four counts:

- **It stays limp.** Silicone has almost no memory, so the wire lies where it is put
  instead of trying to straighten out against the lid.
- **It is finely stranded.** Flexible silicone wire uses many thin strands rather than
  a solid core or a few coarse ones, which is most of where the flexibility comes from.
- **Tinned copper does not fray or tarnish.** The strands stay together when stripped
  and take solder without fuss.
- **It tolerates a soldering iron.** Silicone is good to around 200 C. PVC shrinks back
  from the heat and can leave bare conductor near the joint, which matters most on
  short leads where the iron is close to the insulation. In a sealed metal-free box the
  consequence is not dramatic, but a receded jacket next to a 3.3 V rail is still a
  thing you would rather not build in.

This is a requirement, not a nice-to-have. There is very little spare volume, the board is retained by nothing but the clamshell ridges, and stiff wire pushing back against the lid is enough to lift it out of them. Building this with ordinary PVC hookup wire is doomed, not merely awkward.

Wiring itself is unchanged from bring-up: eight conductors, no passives, no level
shifting. The pinout is in [hardware.md](hardware.md#wiring).

## The 25-degree stand

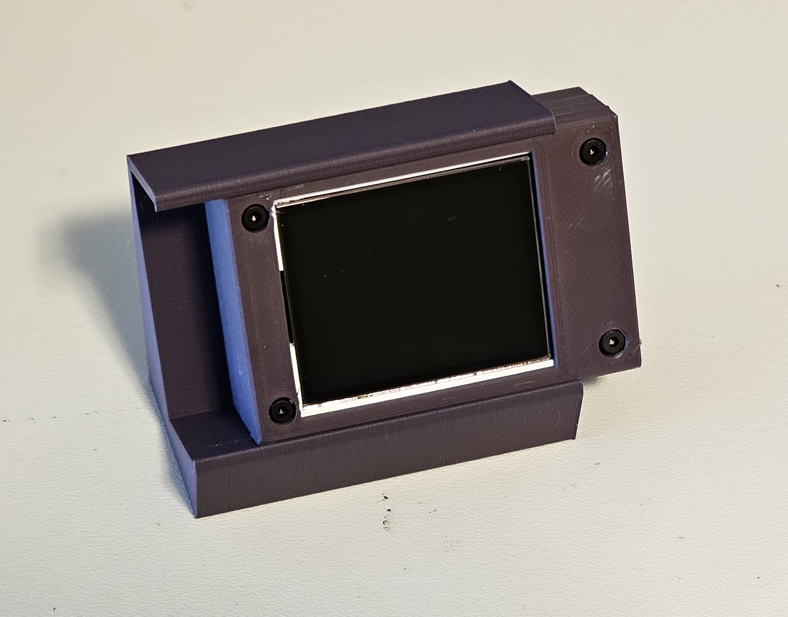
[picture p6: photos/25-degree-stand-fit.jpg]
The case in the 25-degree stand


Optional, and independent of everything above: the case is complete without it. Flat on
the desk the screen points at the ceiling, which is fine if the beacon sits below eye
level and wrong everywhere else. The stand tilts it back 25 degrees so the panel faces
you from a normal seated position.

It is one part: a single profile extruded 60 mm, which is the case's long edge.

**The case is held by friction alone.** The body drops into the slot and stays there;
there are no screws, no clips, and no features on the case that the stand engages. That
follows from the clamshell being finished before the stand existed, and it is the reason
the stand is a separate object rather than a revision of `back`: you can print one, not
print one, or print a different one, without touching a case that already fits.

A friction fit is a tolerance fit, so it is the one thing here that may not transfer
between printers. If yours comes out loose, scale the slot rather than the part.

## Print settings

These are the settings that produced the parts that fit.

| | Clamshell (`front`, `mid`, `back`) | Stand |
|---|---|---|
| Printer | Prusa i3 MK3S | Prusa i3 MK3S |
| Nozzle | 0.4 mm | 0.4 mm |
| Layer height | 0.10 mm, the stock **DETAIL** preset | 0.20 mm, the stock **SPEED** preset |
| Material | PLA | PLA |
| Infill | 20% | 15% |
| Supports | none | none |

**Orientation:** largest flat face down for each part. The geometry makes it obvious;
there is no overhang to argue about, on either the clamshell or the stand.

**0.10 mm is the only layer height the clamshell has been printed at.** It is not known
to be necessary. The parts are small enough that a finer layer costs little time, so
there was never a reason to experiment, and the fit was tuned at this setting. Whether
0.15 or 0.20 mm also fits is simply untested. If you print coarser and something binds,
come back to 0.10 before suspecting the model, since that is the only combination known
to work.

**Infill was not tuned.** The clamshell has only been printed at 20% and the stand only
at 15%. Neither number was chosen; they are what the slicer was already set to. These
are small solid-walled parts with no load path through the infill, so the two are very
unlikely to differ in any way you could measure. Recorded here because it is what was
actually run, not because it is a requirement.

## Two builds

**The Nano ESP32 build** came first because the board was on hand and the display
wiring was already proven on it in `env_monitoring`. It is complete, in daily use, and
the reference the other build is measured against.

**The RP2040-Zero build** exists because the Nano is overkill here. Its Wi-Fi and
Bluetooth are most of what it costs, and this project uses neither: everything travels
over USB by design, and [not adding a network](architecture.md#non-goals-for-now) is a
deliberate choice rather than an unfinished one. A Waveshare RP2040-Zero is far smaller
and cheaper, has USB-C, and is 3.3 V logic, so the display still needs no level
shifting.

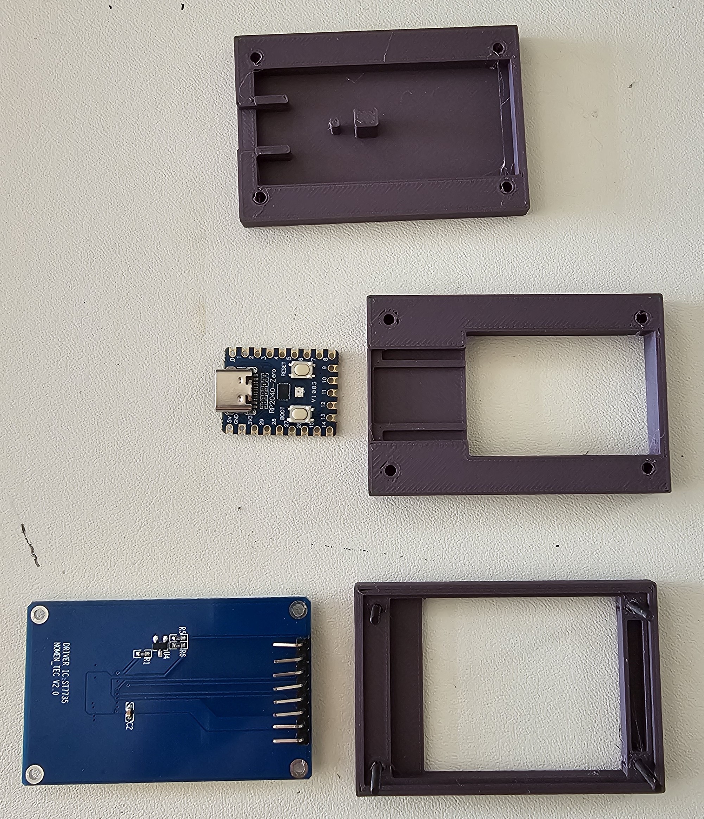
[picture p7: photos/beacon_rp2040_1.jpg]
The RP2040-Zero build's parts


Everything in the RP2040 build, before assembly: `back-rp2040-v0` with the ridges that
retain the board, the bare RP2040-Zero, `mid-rp2040-v0`, the display module with its
header still straight, and `front-v0`, which is the one printed part both builds share.
The board's own labels are legible here, and they are what the wiring table names: `5V`,
`GND`, `3.3V`, then bare GPIO numbers down the left edge.

The RP2040-Zero wired into its case

The same board wired and seated. Eight silicone conductors run from the display's header,
bent flat as on the Nano, to one edge of the board, and the ridges close onto the bare
PCB to hold it. The USB-C cutout is the only opening in the finished case.

What differs between them:

- **Mid and back parts.** The ridges that retain the board are shaped to its outline,
  so each board has its own pair. The front, the stand, the screws and the outside
  dimensions are shared.
- **Wiring.** Same eight display wires, different pads on the board. See
  [hardware.md](hardware.md#wiring).
- **Firmware.** Pins, the SPI bus and some USB serial details are board-specific. The
  host daemon is the same for both.

Both builds are complete and interchangeable: same display, same daemon, same firmware
from the same source, and the same 40 x 60 x 19 mm case from the outside. What the port
involved is in the [roadmap](roadmap.md#the-rp2040-zero-edition).

## Versioning

Every part is suffixed `-v0`, the stand included. That is the revision that was fitted
and works. A part cut for one board carries the board in its name before the version,
as in `mid-rp2040-v0`; a part without one, like `front-v0`, is shared by both builds,
and the Nano's own parts keep the plain names they had before there was a second build. If a part is revised, add `-v1` rather than overwriting, and revise all three
formats together so they cannot drift apart.

The reason for keeping old versions rather than relying on history: none of these
formats diff usefully. SolidWorks parts are binary containers, and while STEP is
technically a text format, a diff of a few thousand renumbered geometry entities tells
you nothing. Git can store all of them faithfully; it just cannot tell you what
changed. An old file sitting next to the new one is the only practical way to compare
or fall back.

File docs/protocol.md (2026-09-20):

# Host to device protocol

USB CDC serial, 115200 baud, newline-delimited JSON. One message per line, UTF-8, compact (no whitespace). Host to device only in phase 1. An optional device heartbeat is described at the end.

Design goals: readable on a serial monitor, trivial to parse with ArduinoJson, and a full snapshot with 6 sessions fits in one line well under 1 KB.

## Snapshot

Sent whenever host state changes, and at least once per second regardless, so the ages on screen keep advancing. The host does not check whether anything is happening first: the snapshot is small and the device repaints only the fields that changed, so an idle desk costs a line a second and no drawing. The device replaces its entire view with each snapshot. There are no deltas.

```json
{"t":"snap","v":1,"ts":1725480000,"n":4,"cost":4.2,"sel":1,"rl":{"h5":92,"d7":28},
 "s":[
  {"id":"a1b2c3d4","l":"session-beacon","st":"work","age":120,"ctx":62,"m":"fable5.1"},
  {"id":"e5f6a7b8","l":"env_monitoring","st":"held","age":840,"ctx":41,"m":"opus"},
  {"id":"c9d0e1f2","l":"homelab","st":"idle","age":5},
  {"id":"a3b4c5d6","l":"data-pipeline","st":"stale","age":360}
 ]}
```

Top level:

| Field | Type | Meaning |
|---|---|---|
| `t` | string | Message type. `snap` for snapshot. |
| `v` | int | Protocol version. Device shows an error on an unknown version. |
| `ts` | int | Host unix time. Informational. |
| `n` | int | Total live sessions on host. May exceed the length of `s` if truncated. |
| `cost` | float | Sum of `total_cost_usd` across live sessions. Omitted if unknown. |
| `sel` | int | Index into `s` of the featured session shown in the footer. Host picks the most urgent. |
| `s` | array | Sessions, already sorted by the host in display order. Max 6. |
| `rl` | object | Account usage: `h5` and `d7` are used percentages for the rolling five-hour and seven-day windows. Either key may be absent. Omitted entirely when no statusline has reported in the last five minutes, because a stale percentage is worse than none. |

Session object:

| Field | Type | Meaning |
|---|---|---|
| `id` | string | First 8 chars of `session_id`. The device stores it and does not currently use it; rows are matched by position. Useful when reading a snapshot on a serial monitor. |
| `l` | string | Label, max 16 chars. The host shortens longer ones from the middle, keeping 9 chars from the start and 5 from the end around `..` (`inventory-service2` becomes `inventory..vice2`), because clones of one repo usually differ only in a suffix. |
| `st` | string | `start`, `work`, `need`, `held`, `look`, `wait`, `err`, `idle`, `stale`, `end`. Drives the row's dot colour. `need` and `held` fill the whole row; only `need` pulses. |
| `age` | int | Seconds in current state. Across `need`, `held` and `wait` it keeps running rather than restarting at each rung, so it is the whole time the session has been waiting on a human. A `look` row that graduates to `need` starts again at zero, because time spent in `look` was not time spent waiting on a human. |
| `ctx` | int | Context window used, percent. Optional. |
| `m` | string | Model short name, max 8 chars. Optional. Shown only for the featured session. |
| `tool` | string | Last tool name, max 10 chars. Optional. The host sends it whenever it knows one; the device does not read it yet, because a row has no space for it. See [roadmap.md](roadmap.md). |

## Other host messages

```json
{"t":"hello","v":1,"host":"IGOR-PC"}
```
Sent on connect and reconnect. It refreshes the device's last-message timestamp, which is what stops the "no host" screen appearing; the screen is actually cleared by the next snapshot, since `hello` carries nothing to draw.

```json
{"t":"bl","pct":40}
```
Backlight brightness 0 to 100. Ignored until BL is wired to a PWM pin.

## Device to host (optional)

```json
{"t":"hb","fw":"0.3.0","board":"rp2040-zero","up":3600,"rx":142,"bad":0,"drop":0,"txdrop":0,"aflip":1,"wedge":0,"wcause":"none","wflip":0,"since":412,"render":1,"spi":"hw","rst":"power"}
```
Heartbeat every 3 s. `txdrop` and `rst` were added in firmware 0.2.0, `aflip` and `wedge` in 0.2.1, `wcause` and `wflip` in 0.2.2, and `board` in 0.3.0; the host treats all seven as optional.

| Field | Meaning |
|---|---|
| `fw` | Firmware version |
| `board` | Which build sent this: `nano-esp32` or `rp2040-zero`. The rest of the protocol is identical on both |
| `up` | Seconds since boot |
| `rx` | Lines accepted |
| `bad` | Lines that failed to parse |
| `drop` | Lines discarded for exceeding the buffer |
| `txdrop` | Outgoing lines dropped because the USB pipe was not draining while a host held the port |
| `aflip` | Times the device's view of "a host holds the port" has changed since boot. 1 after an ordinary connect. A climbing count is a flapping link |
| `wedge` | Times the device has rebooted itself to recover a dead serial return path. Kept across that reboot, so it is a lifetime count, not a since-boot one |
| `wcause` | What the last of those reboots saw, kept with `wedge`: `det` if the device believed no host held the port, `att` if it believed one did but nothing it wrote was being collected, `none` if there has been none |
| `wflip` | How many times that belief changed during the last such episode. Many means a flapping link rather than a stuck one |
| `since` | Milliseconds since the last accepted message |
| `render` | Duration of the most recent repaint, ms |
| `spi` | `hw` or `sw`, which SPI path is compiled in |
| `rst` | Why the board last reset. `power`, `sw` (the device's own cure, see `wedge`), `brownout` or `other` on either board; `panic`, `int_wdt`, `task_wdt` or `wdt` on the Nano ESP32; `wdt`, `run_pin`, `debug` or `glitch` on the RP2040-Zero. A watchdog reset or `panic` means the watchdog rescued a hung `loop()`, except on the first boot after flashing an RP2040-Zero, where the bootloader reboots the same way. |

These exist because a quiet host and a device that is dropping or failing to parse lines look identical from the outside: a screen reading "no host".

The host acts on the heartbeat as well as logging it. If the port is open and no heartbeat has arrived for 15 s, counting from the later of the port opening and the last heartbeat, the device state is `silent`. `/health` then reports `"device": false`, the status line says `beacon silent`, and the daemon logs one warning. If `up` goes down between heartbeats, even across a reconnect, the host logs a reboot and its `rst`; if `wedge` goes up, it logs that the board recovered its own return path, and which of `wcause`'s two faults it was.

`silent` does not mean the display has stopped. It means only that nothing is coming back, which is equally consistent with a sketch that has stopped and with a return path that has died under a display still rendering every snapshot it is sent. The host cannot separate those and does not pretend to; the device can, and cures the second itself. See [architecture.md](architecture.md).

The device never blocks to send a heartbeat. If the pipe is not draining, lines are dropped and counted in `txdrop`.

## Rules

- Lines longer than 1024 bytes are discarded by the device, including the remainder after the overflow, and counted in the heartbeat's `drop`.
- Unknown fields are ignored on both sides. Add fields freely; bump `v` only for breaking changes.
- A new `st` value is not a breaking change. The device falls back to `start`'s grey for anything it does not recognise, so an old device driven by a new host renders the new state plainly rather than failing. `held`, `wait` and `look` were added this way: bumping `v` for them would have replaced a grey dot with a full-screen `protocol` error on every device not yet reflashed, which is the worse outcome by a wide margin. Bump `v` when the device would otherwise draw something *wrong*, not merely something dull.
- The device shows a "no host" screen after 10 s without any message.
- No ACKs. A corrupted line is fixed by the next snapshot.

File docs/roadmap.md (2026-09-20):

# Roadmap

**Where this stands:** the beacon has been in daily use since early September, and
there are now two complete builds. Both run firmware 0.3.0 from one source, on the same
daemon, hooks, enclosure family and stand: the original **Arduino Nano ESP32** and a
**Waveshare RP2040-Zero**, which is smaller and cheaper and gives up nothing the project
uses.

The document goes from what is open to what is already done: the smaller open items, the
things decided against, the recent hardening work, and then the history.

## Smaller open items

These are display work. The data is already there, so each item needs a layout decision
rather than plumbing.

- **Last tool name per row.** The host records it and the protocol carries a `tool`
  field, but nothing draws it. There is no room on a row without giving up label width.
- **"More below" indicator.** With more than six sessions, the host sorts and truncates
  correctly and the header's active count reveals the overflow. Nothing on the screen
  says there are more rows.
- **Subagent count on a row.** The host already tracks how many are outstanding
  (`SubagentStop` is registered).

## Maybe later

- Session history: how long each session spent waiting on you today. This would need a
  tiny SQLite store in the host.
- Linux host support. Only the hook command line and the serial device path differ.
- Tray icon for the daemon, with "show log" and "quit".
- A second page, or scrolling, for more than six sessions, driven by a button on the
  device.

## Decided against

- **Piezo or LED cue on `NEEDS_INPUT`.** Not wanted. The red row and its decaying pulse
  are enough.
- **Backlight on a PWM pin, dimming when idle.** The panel's brightness is fine as it
  is, and this would mean moving a wire. The protocol's `bl` field stays reserved and
  ignored.
- **Native `http` hooks in place of `curl`.** `statusLine` is command-only, so `curl`
  would stay on the busiest path either way. The events it would save cost under a
  second an hour in total. See
  [architecture.md](architecture.md#native-http-hooks-were-evaluated-and-not-adopted)
  for the evidence and for what would change the answer.
- **Wi-Fi, MQTT, cloud.** USB only, by design. See
  [non-goals](architecture.md#non-goals-for-now).

## Recent hardening (7–18 September)

Once the beacon was in daily use, it began showing the wrong thing in ways a test bench
never would. Every fix below started from a real observation or a captured payload, and
each is guarded by a test, a fixture or a rule in `CLAUDE.md`.

| Date | What was seen | Cause | Fix |
|---|---|---|---|
| 09-07 | Two sessions pulsed red for thirteen hours | The alarm never decayed | [The attention ladder](architecture.md#the-attention-ladder): two minutes of pulse, eight of red, then amber sorted below the working sessions |
| 09-07 | A turn waiting on a subagent went red | `Stop` was read as idle even with background work pending | `background_tasks` keeps it `WORKING` and holds back `idle_prompt` |
| 09-07 | A prompt answered "no" left the row red | A rejection runs no tool, so no `PostToolUse` arrives | `PostToolBatch` registered: it is the only event that arrives when a human answers |
| 09-07 | Waiting sessions vanished on every daemon restart | State lived only in memory, and a parked session sends nothing | Written to `sessions.json` atomically, restored at start |
| 09-08 | A session blocked on you showed blue | A subagent's events carry the parent's `session_id` | Tell them apart by `agent_id`. `SubagentStop` recomputes the count |
| 09-09 | A finished session showed blue, then amber, never red | An armed artifact comment monitor counted as work that never ends | Count only `subagent` tasks ([details](claude-code-integration.md#background_tasks-is-not-only-subagents)) |
| 09-10 | An orchestrator waiting on a workflow went full red | One severity for two different messages | [A cyan `look` rung](architecture.md#the-soft-rung-needs_look) for "quiet a while", which graduates to red after `look_s` |
| 09-10 | A session killed by Windows Update stayed on screen for 45 hours | Restored from disk as though it were parked | Nothing is restored across a reboot, and anything silent for 24 hours is dropped |
| 09-16 | The display froze eight times in eight days while `/health` said ok | The heartbeat's `printf` blocked forever on a USB pipe that had stopped draining | A non-blocking tx queue and the loop watchdog. The host reports `silent` ([details](architecture.md#usb-writes-must-never-wait)) |
| 09-17 | "Replug" shown for two hours against a board that was working | Only the return path was dead | `txWatchdog()` reboots the board to re-enumerate ([details](architecture.md#a-silent-board-is-not-a-frozen-one)) |
| 09-18 | A window closed after its turn stayed green for a day | Only `WORKING` had a staleness timer | `IDLE` with no event for `idle_stale_s` (10 min) goes stale |
| 09-18 | A daemon restart after flashing silently did nothing | A daemon started by hand was invisible to the Scheduled Task | `scripts/restart-daemon.ps1` is the only way to restart it, and `/health` reports the pid |
| 09-18 | No heartbeat for five hours while the board rendered every snapshot, and `txWatchdog()` never fired | It trusted `hostAttached()`, which read true over a FIFO that never drained, or kept flickering back to true | The watchdog trusts bytes written instead. Each cure records `wcause` and `wflip`, and `stall` tests the new path. Firmware 0.2.2 ([details](architecture.md#a-silent-board-is-not-a-frozen-one)) |

## How we got here

**Phase 0: scoping (4 Sep).** Docs, repo layout, protocol, skeletons.

**Phase 1: blink the beacon.** Captured real hook payloads, which disagreed with the
published schema in four places, and committed them as fixtures. Brought up the panel,
which turned out to be BGR-wired. Built the firmware renderer, the host state machine,
the hook server and the serial link. Hooks forward with `curl`. The first hardware bug
was an unsigned `millis()` underflow that painted "no host" over every frame.

Exit criteria, which still define correct behaviour:
- leaving a session on a permission prompt turns its row red within one second
- answering it turns it blue
- `Stop` turns it green
- left unanswered, the pulse stops after two minutes and the red after ten

**Phase 2: make it a daily driver.**
- COM port auto-detected by VID/PID, with reconnect after a reflash or unplug.
- Runs at logon as a Scheduled Task and logs to a rotating file.
- Hardware SPI at 24 MHz, with in-place field drawing instead of clear-then-draw, which
  ended a once-a-second flash.
- Sessions labelled by git repository, with overrides in config.
- The footer alternates between session context and cost, and the account's five-hour
  and seven-day usage ([details](architecture.md#the-footer-alternates)).
- A three-part printed enclosure and a 25-degree stand ([enclosure.md](enclosure.md)).
- An uninstall script that undoes everything the installers did.

**Phase 3** is the list in "Recent hardening" above. None of it was planned; all of it
came from living with the device.

## The RP2040-Zero edition

**Why.** Most of what the Nano ESP32 costs is its Wi-Fi and Bluetooth, and this project
uses neither on purpose ([non-goals](architecture.md#non-goals-for-now)). The
RP2040-Zero is far smaller and cheaper, has USB-C, and is 3.3 V logic, so the display
still needs no level shifting. The ground rules were that the protocol does not change,
the firmware stays dumb, and the Nano build stays supported as the reference.

**One sketch, not two.** Almost every hard-won rule in `CLAUDE.md` lives in the shared
rendering and parsing code, and two copies would let the fixes drift apart. Only four
things sit behind `#if defined(ARDUINO_ARCH_RP2040)`: the pins and SPI bus,
`hostAttached()`, the platform block (reset reason, reboot, loop watchdog) and where the
wedge counters live.

**What the port turned up**, none of it assumed from the ESP32 findings:

- The RP2040 core's `write()` gives up after a second rather than blocking forever, so
  the fault that froze the Nano eight times in eight days cannot happen here. Both
  builds keep the tx queue anyway: a second is still most of a frame.
- `Serial` as a boolean is `tud_cdc_connected()`, the same predicate the Nano build
  spells out by hand, so `hostAttached()` can use it. The warning against `if (Serial)`
  is about the ESP32 core's separate flag and does not carry over.
- There is no RTC memory, so the counters that outlive a cure live in the watchdog's
  scratch registers 0 to 3. Registers 4 to 7 hold what the SDK leaves the bootrom.
- `rp2040.reboot()` is itself a watchdog reboot and `getResetReason()` cannot tell it
  from the loop watchdog firing, so a cure marks itself and `resetReason()` reads and
  clears that mark at boot. Found on the board, where every cure reported `rst` as
  `wdt`.
- The bootloader trigger is a 1200-baud open, not a DTR/RTS pattern. The daemon never
  changes the baud rate, so the rule that the host never revives a board through the
  port is unchanged.

**Verified on the assembled unit**: the smoke test's geometry, text and layout mock at
24 MHz, with the same BGR fix the Nano's panel needs; `hang` rebooting it in 5.0 s; and
`scripts/wedge-bench.py` passing both `stall` (`wcause=att`) and `wedge` (`wcause=det`),
each rebooting 30.2 s in with the count surviving. The same three tests pass unchanged
on the Nano, which is the evidence that one sketch for two boards cost the reference
build nothing. The daemon finds either board by USB id, and the heartbeat's `board`
field names the one that answered.

The enclosure is `mid-rp2040-v0` and `back-rp2040-v0`, sharing `front-v0`, the stand,
the M2 x 16 screws and the 40 x 60 x 19 mm envelope with the Nano build. The two cases
are identical from the outside, which is why there is no separate photo of the finished
unit; the build-stage photos are in [enclosure.md](enclosure.md#two-builds).

## Open questions

- **The null context case is untested on real data.** `used_percentage` is null early in
  a session and after `/compact`. The token-count fallback that covers it has only been
  exercised by unit tests. See
  [claude-code-integration.md](claude-code-integration.md#still-to-confirm).

Settled since the last revision:
- **RP2040: one sketch or two?** One, with a thin per-board layer. See
  [the RP2040-Zero edition](#the-rp2040-zero-edition).
- The statusline carries the context percentage directly.
- Hooks run fine through the `curl` command lines on Windows.
- `idle_nag_s` was never needed. Claude Code's own `idle_prompt` arrives a few minutes
  into an idle wait and climbs the attention ladder, and `idle_stale_s` handles a window
  that was closed instead.

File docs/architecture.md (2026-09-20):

# Architecture

## Components

| Component | Where | Language | Responsibility |
|---|---|---|---|
| `beacon-hook` | `hooks/beacon_hook.py` | Python | Invoked by Claude Code on every hook event. Reads the JSON payload from stdin, POSTs it to the daemon, exits fast. Must never block Claude Code. |
| `beacon-host` | `host/src/beacon_host/` | Python | Long-running daemon. Receives hook events, maintains per-session state, talks to the device over USB serial. |
| firmware | `firmware/beacon/` | Arduino C++ | Reads newline-delimited JSON from USB serial, renders to the ST7735. No policy, no state beyond the last snapshot. |

## Why a daemon in the middle

Hooks are short-lived processes with no shared memory. Something has to own the serial port, hold state across events, and debounce redraws. Options considered:

- **Hook writes directly to serial.** Rejected. Multiple sessions would fight over the COM port, and no process would know the full picture.
- **Hook appends to a spool file, a separate script polls it.** Workable but adds file locking and a second process anyway.
- **Hook POSTs to a localhost HTTP daemon.** Chosen. One owner of the port, one owner of state, a cheap hook. If the daemon is down the POST fails instantly and the hook is a no-op.

### The forwarder is curl, not a script

Hooks run synchronously and the busiest of them fires on every tool call in every session, so the forwarder's process startup is the cost that matters. Measured on this machine, posting one event:

| Forwarder | Median | p90 |
|---|---|-----|
| `curl.exe` from System32 | 15.6 ms | 28.1 ms |
| Python, system interpreter | 99.1 ms | 107.0 ms |
| Python, project venv | 121.9 ms | 134.7 ms |

curl ships with Windows, so this also removes any dependence on which Python is on `PATH` and any need to activate a virtual environment from a hook. The hook command is a single unquoted line.

`hooks/beacon_hook.py` remains as a portable fallback for machines without curl, and `hooks/capture_payloads.py` exists to record real payloads for fixtures.

### Native HTTP hooks were evaluated and not adopted

Claude Code has a native `http` hook type that would POST the payload to the
daemon with no process at all. It was checked against both the published
[hooks reference](https://code.claude.com/docs/en/hooks) and the CLI binary on
this machine (2.1.261), because in this project the binary has already been
right where the docs were wrong. The feature is real: `HttpHookSchema` takes
`url`, `timeout` in seconds, `headers` and `allowedEnvVars`, and a localhost
target is explicitly blessed rather than tolerated — the binary carries the
string "Loopback (127.0.0.1, ::1) is allowed for local dev". It was still not
adopted, for four reasons.

**The status line cannot follow.** `statusLine` accepts `"type": "command"` and
nothing else, so `curl.exe` stays on a path that runs on every status refresh
whatever the events do. Moving the nine lifecycle events to `http` halves the
process spawns at best; it does not remove the dependency, which was the point.

**The saving is below the noise floor.** `/health` reported 56 hook events in
60 minutes of ordinary use. Against the 15.6 ms median above, that is under a
second of added latency per hour, arriving as 56 separate 15 ms moments. The
8x margin over a Python forwarder in the table is real, but it is 8x of a
number small enough that the table exists to justify a choice already made,
not to chase further.

**Cross-platform config gains little.** The only Windows-specific token in the
hook commands is the absolute path `C:/Windows/System32/curl.exe`; elsewhere it
is just `curl`. The `statusLine` line needs that same edit for a Linux host
regardless, so an `http` block does not shrink the port.

**It would add a silent failure.** An unrecognised hook `type` is answered with
`Unknown hook type "..."` and the hook is skipped. On a Claude Code older than
the one that added `http`, every event would vanish and the display would go
blank — which is the symptom this project already warns is mistaken for a
hardware fault.

Two further details are worth recording so they do not have to be dug out of
the binary again. `async`, "hook runs in background without blocking", is a
field on the **command** hook schema only, not the HTTP one; an `http` hook
still blocks the turn, so it would not have bought non-blocking delivery
either. And an HTTP hook's response must be empty or JSON — "HTTP hook returned
empty body, treating as empty JSON object" — where a command hook's stdout is
free-form. The `timeout` would also have to be set explicitly: the documented
default for `http` hooks is 600 seconds, against `--max-time 1` today, so a
wedged daemon could stall a session instead of failing instantly.

What would change the answer:

- `statusLine` gaining a non-command type. That is the single change that would
  actually take `curl` out of the design, and it makes the rest of the argument
  collapse.
- A Linux or macOS host, where the whole configuration could then be one
  OS-independent block — but only if the status line comes along too.
- Spawn cost becoming visible under many concurrent sessions. This would
  announce itself rather than needing to be hunted: Claude Code warns with
  `Slow PostToolUse hooks:` and `--debug` prints a per-hook `durationMs`.

### The daemon composes the status line

The statusline hook is also plain curl. It POSTs the payload to `/status` and the daemon returns the text to display in the response body, which curl prints. That keeps a second interpreter out of a path that runs on every status refresh.

The reply is composed purely from the payload just received, so the HTTP handler needs no shared state and no locking. The one external fact it uses is the device state, which appears as a marker at the end of the line: `beacon` when the board is answering, `beacon?` when there is no port, and `beacon silent` when the port is open but the heartbeats have stopped. That makes a dead daemon, an unplugged display or a mute one visible in the terminal without looking at the device. The last case is the one the marker is worst at describing, so it describes only what is known: a silent board may be frozen, or may be rendering perfectly with only its return path dead, and the daemon cannot tell. It used to read `beacon stuck: replug` and was shown for two hours against a beacon whose counters were visibly advancing.

`/event` replies `204` with an empty body, deliberately. Claude Code feeds some hooks' stdout back into the session as context, so the forwarder must print nothing. That answer happens to satisfy the HTTP hook contract as well, where a response body must be empty or JSON, so the constraint now has two independent reasons behind it.

## Session state machine

Each session is keyed by Claude Code's `session_id`.

**The label is the enclosing repository, not the working directory.** `cwd` in a hook
payload is the session's live working directory and it moves as you work. Labelling
straight from it meant a session in this repo displayed as `host` the moment anything
ran in `host/`, and because the label was only computed once it then stayed wrong for
the rest of the session. The host now walks up from `cwd` to the nearest ancestor
holding a `.git` entry and uses that name, recomputing whenever `cwd` changes. Results
are cached, since hooks fire on every tool call and this touches the filesystem.

Overrides in the host config are matched against both the exact `cwd` and the resolved
repository root, so keying them by repo root works.

This diagram is written in hook events, for working on the code. The README has
[the same machine as the display shows it](../README.md#what-the-colours-mean).

```mermaid
stateDiagram-v2
    [*] --> STARTING: SessionStart
    STARTING --> WORKING: UserPromptSubmit
    IDLE --> WORKING: UserPromptSubmit
    WORKING --> WORKING: PreToolUse / PostToolUse / PostToolBatch
    STARTING --> NEEDS_INPUT: PermissionRequest / direct-ask Notification
    WORKING --> NEEDS_INPUT: PermissionRequest / direct-ask Notification
    NEEDS_INPUT --> NEEDS_HELD: after need_pulse_s
    NEEDS_HELD --> WAITING: after need_red_s
    NEEDS_INPUT --> WORKING: PostToolBatch / PostToolUse
    NEEDS_HELD --> WORKING: PostToolBatch / PostToolUse
    WAITING --> WORKING: PostToolBatch / PostToolUse
    WORKING --> IDLE: Stop (no subagent running)
    WORKING --> WORKING: Stop (a subagent still running)
    WORKING --> IDLE: SubagentStop (the last one, turn already over)
    WORKING --> IDLE: the background count expires, turn already over
    IDLE --> NEEDS_INPUT: idle_prompt, fresh or released from hold, nothing untracked listed
    IDLE --> NEEDS_LOOK: idle_prompt, fresh or released from hold, untracked work listed
    NEEDS_LOOK --> NEEDS_INPUT: after look_s, or a direct ask
    NEEDS_LOOK --> WORKING: PostToolUse / PostToolBatch / UserPromptSubmit
    NEEDS_LOOK --> IDLE: Stop
    WORKING --> ERROR: StopFailure
    WORKING --> STALE: no event for stale_after_s
    IDLE --> STALE: no event for idle_stale_s
    STARTING --> STALE: no event for idle_stale_s
    STALE --> WORKING: PostToolUse / UserPromptSubmit
    ERROR --> WORKING: UserPromptSubmit
    STARTING --> ENDED: SessionEnd
    WORKING --> ENDED: SessionEnd
    IDLE --> ENDED: SessionEnd
    NEEDS_LOOK --> ENDED: SessionEnd
    NEEDS_INPUT --> ENDED: SessionEnd
    NEEDS_HELD --> ENDED: SessionEnd
    WAITING --> ENDED: SessionEnd
    ERROR --> ENDED: SessionEnd
    STALE --> ENDED: SessionEnd
    STALE --> ENDED: process exited, or /forget
    ENDED --> [*]: after grace period
```

"Direct ask" means `PermissionRequest`, or a `Notification` of type
`permission_prompt`, `elicitation_dialog`, `elicitation_url_dialog` or
`agent_needs_input`. "Untracked work" is any live `background_tasks` entry other
than a `subagent`, a `monitor`, `dream` or `auto-mode scan`; see
[the soft rung](#the-soft-rung-needs_look).

State semantics:

| State | Meaning | Colour |
|---|---|---|
| `STARTING` | Session opened, no prompt yet | grey |
| `WORKING` | Claude is running (thinking or using tools) | blue |
| `NEEDS_INPUT` | Blocked on a permission prompt, or idle-waiting for you after a notification. The first two minutes of it | red, pulsing |
| `NEEDS_HELD` | Same thing, two to ten minutes in | red, static |
| `WAITING` | Same thing, over ten minutes in | amber |
| `NEEDS_LOOK` | Claude has gone idle, but a workflow, a background shell or similar is still running. Joins `NEEDS_INPUT` after `look_s` (default 300 s) | cyan |
| `ERROR` | The turn ended on an API error such as a rate limit or an overload | magenta |
| `IDLE` | Claude finished its turn, waiting for the next prompt | green |
| `STALE` | Expected to hear from the session and did not: `WORKING` with no event for `stale_after_s` (default 300 s), or `IDLE`/`STARTING` with none for `idle_stale_s` (default 600 s) | amber |
| `ENDED` | Session closed; kept on screen briefly, then dropped | dim grey |

`Stop` means the turn ended, not that a human is needed: it carries `background_tasks`, and a turn that ends with a subagent still running stays `WORKING`. Calling it `IDLE` let the next `idle_prompt` paint a red row with nothing to act on. See [claude-code-integration.md](claude-code-integration.md#hook-events-we-register).

**Only a subagent counts.** `background_tasks` is every kind of in-flight work the
session has registered — `subagent`, `shell`, `monitor`, `workflow`, `MCP task`,
`teammate`, `cloud session` — and reading it as "subagents still running" cost a
session eight minutes of blue followed by amber while it sat waiting on a human. It
had no subagents at all. It had two armed artifact comment monitors, which register
as `monitor` tasks for the life of the session.

The reason only `subagent` counts is not that the others are less real. It is that
the beacon has machinery for exactly one of them: `SubagentStop` retires a subagent,
and a subagent's own hook events refresh the freshness stamp. Nothing announces the
end of any other type, so counting one is a guess that can only mute the display,
and a `monitor` never ends at all — the count could only ever go up, and a session
that had used the artifact tooling could never be shown as waiting on you again.
An unrecognised `type` is ignored for the same reason: a wrongly ignored task shows
a red row that de-escalates in ten minutes and clears on the next tool call, while a
wrongly counted one that never ends silences the session for good.

**That count has to be able to come back down.** It used to be recomputed only on
the next `Stop` or `UserPromptSubmit`, and a turn that has already ended and is
waiting on you produces neither -- so a count left positive suppressed every
`idle_prompt` the session would ever send, and the row stayed blue however long you
left it. `SubagentStop` is registered for exactly this: it fires when a subagent
ends, carries a fresh `background_tasks`, and drops the row to `IDLE` when it was
the last of them and the turn was already over.

**And the hold expires in `tick()`, in one place.** A count nothing has confirmed
for `bg_quiet_s` (default 180 s) is retired outright: the row hands back to `IDLE`
if its turn was already over, and whatever the count was suppressing is released. A
running subagent refreshes the stamp constantly with its own hook events, so a
genuinely busy session is never escalated. Doing this in `tick()` rather than inside
the branch that consults the count is what makes `IDLE` reachable at all — the
alternative was the row sitting on `WORKING` until the staleness timer turned it
amber, which is the worst answer available, because `stale` sorts *below* `work`.

**A held `idle_prompt` is not a lost one.** It used to be dropped, on the assumption
that a later one would get through. Claude Code sends them "after Claude has been
waiting a while", which sounds like a repeat and is not a promise of one: for the
idle period that turned this up it sent exactly one, 183 seconds after the turn
ended, against a 180-second hold that had re-armed itself at the `Stop`. Three
seconds decided whether the row was ever red. It is now remembered on the session
and delivered when the hold expires or the count retires, so which side of the
window it lands on no longer matters and nothing depends on a second one arriving.

`STALE` catches crashed or killed VS Code windows that never sent `SessionEnd`. `ENDED` sessions are dropped after `ended_grace_s` (default 30 s).

**`STALE` is reachable from `IDLE` and `STARTING` too.** It used to fire only from
`WORKING`, so a window killed after its turn had ended sat green, age climbing, with
nothing short of the 24-hour ghost cutoff to remove it. A green row lies about
liveness more convincingly than any other, because green is exactly what a parked
live session looks like. What separates the two is the `idle_prompt`: a live session
sends one a few minutes after its turn ends (183 s in the capture), and that takes
it off `IDLE`. A row still `IDLE` with no event of any kind for `idle_stale_s`
therefore has nothing left to send one. The timer runs from `last_event`, so an
informational notification counts as a sign of life.

It lands on `STALE` rather than a new state because `STALE` already means "expected
to hear from this session and did not", which is the claim here too, and because a
wrong guess costs almost nothing: a live parked session reaches amber through the
ladder about ten minutes after its `idle_prompt`, and the next event of any kind,
including a late `idle_prompt`, moves the row on. `STARTING` is included on the same
terms; a session opened and closed before its first prompt otherwise sat grey for a
day.

**A killed session ends when its process does.** Closing a window or ending the
process sends no `SessionEnd`, so a killed session went `stale` or rode the ladder
down to `wait`, and then stayed on screen until the 24-hour ghost cutoff, looking
exactly like a session parked on purpose. No timeout can fix that, because silence
is all a timeout has and silence is the same in both cases. So the daemon now asks
the OS instead.

No hook payload carries a PID, and the hooks are left alone. The forwarder is
`curl.exe`, which stays connected while its request is handled. The TCP table names
curl's PID, and walking up the process tree (curl, a shell or two, then `claude.exe`)
reaches the process that owns the session. `procwatch.py` does this once per session
and again on every `SessionStart`, because a resumed session runs in a new process.
It does not run on tool events: it costs tens of milliseconds on the hook's clock.
Every 30 s the main loop checks each known PID, and a process that has definitely
exited ends its session as a `SessionEnd` would. The row reads `end` and is gone 30 s
later.

Windows recycles PIDs, so a PID is only trusted together with its creation time.
The walk also stops at any "parent" younger than its child, since that is a
parent PID that has been reused. Anything short of a definite answer (access
denied, an unknown PID, a chain that does not reach `claude.exe` or `node.exe`)
counts as alive. The check can only shorten the wait, never lengthen it. A wrong
"alive" costs nothing new, because the 24-hour cutoff still applies, while a wrong
"dead" would hide a session that may be waiting on you.

`POST /forget` is the manual override for anything the check cannot see. Its body
is a session id prefix of at least four characters or an exact label, as `/health`'s
`rows` show them, and it ends exactly one session or none. An ambiguous key returns
409 with the candidates rather than a guess.

`ERROR` exists because without it a rate-limited session keeps looking busy until the staleness timer fires minutes later, which reads as a dead editor rather than as something that stopped and is waiting for you. Sort order puts it just below the red rungs of the attention ladder.

### The attention ladder

A session waiting on a human used to pulse red until something happened to it,
and nothing in `tick()` ever retired that state. On this machine `/health`
caught two sessions that had been pulsing for **13 hours and 9.7 hours**. Leaving
a session parked is the normal way to work, so an alarm that never stops is
wrong far more often than it is right, and an alarm that is usually wrong stops
being read at all.

`NEEDS_INPUT` is therefore three rungs, timed from when the session entered the
family, not from the previous rung:

| Rung | Elapsed | Treatment |
|---|---|---|
| `NEEDS_INPUT` | 0 to `need_pulse_s` (120 s) | Filled red, pulsing |
| `NEEDS_HELD` | to `need_red_s` (600 s) | Filled red, static |
| `WAITING` | after that | An ordinary row with an amber dot |

Four details are load-bearing, and each looks like a mistake until you know why.

**Only the agent that raised a prompt can end the wait.** A subagent's hook events
carry the *parent's* `session_id`, so treating them as the parent's own repainted a
genuinely blocked row `WORKING` on every tool call the subagent made -- a session
waiting on you could show blue indefinitely, which is the one thing the device is
for. A tool event now clears an attention state only when its `agent_id` matches
the one recorded when the session entered the family (`""` being the main thread).
`PostToolBatch` still clears a prompt answered with feedback, and a subagent's own
`PostToolBatch` still clears a prompt that subagent raised. The event refreshes the
staleness timer regardless, because a long subagent run is the only traffic its
session produces.

**Re-entering the family does not restart the ladder.** `idle_prompt` fires
whenever Claude has been waiting a while, so an unanswered session is notified
again and again. Re-arming on each notification would pulse forever, which is
the exact behaviour the ladder removes. This is observed, not inferred: two
`idle_prompt` notifications were captured for the same session minutes apart with
no answer in between, which is how a row stays red for 13 hours. `_want_attention()` starts the ladder only on entry from
outside; a tool call, a prompt or a `Stop` is what re-arms it.

**The rungs do not reset `state_since`.** Every other transition goes through
`set_state()`, which does. Here `state_since` is both the age on screen and the
ladder's own origin, so resetting it would restart the age mid-wait and re-base
the second threshold, putting `wait` twelve minutes in instead of ten.

**`WAITING` sorts below `WORKING`, next to `STALE`.** It is where sessions left
idle on purpose end up, so ranking it with the alarm states would park them in
the top rows permanently and push actively working sessions off a six-row
display. That is the same noise in a different place. Sinking the last rung is
what makes the ladder subtract from the display rather than rearrange it.

`WAITING` and `STALE` are drawn identically, which is a decision rather than a
collision. "Busy but gone quiet" and "waiting on you for a while" ask a person
for the same thing — look at this one when you get a chance — and in both the
age is the informative part. They stay distinct on the wire so `/health`, the
docs and the sort can tell them apart.

Both thresholds are config, next to `stale_after_s`.

### The soft rung: NEEDS_LOOK

An orchestrator session, `inventory-service2`, went filled red and pulsing while
it waited on a background `workflow` task. Nothing was blocked. The row cleared
itself the moment the session's own thread touched a tool again. The mechanism is
the subagent false alarm again, one task type wider: only `subagent` is counted,
so the `Stop` read as "nothing running", the row went `IDLE`, and the next
`idle_prompt` skipped the hold and took the full alarm.

Widening the count is not the fix. Only a subagent can be retired (`SubagentStop`)
or confirmed alive (its own `agent_id` events), so counting anything else can only
mute the display, and a `monitor` never ends. That is the lesson of the monitor
bug above, and it still stands.

What was actually wrong is that the ladder had one severity for two different
messages. A permission prompt says "I cannot go on without you". An
`idle_prompt` says only "the main thread has been quiet a while", and while real
work is still running somewhere, that deserves a glance, not an alarm. So:

- A second count, `bg_other`, is kept beside `bg_tasks`. It holds live
  `background_tasks` entries that are neither a `subagent` nor work that never
  ends (`monitor`, `dream`, `auto-mode scan`). It **never** decides `WORKING`
  against `IDLE`. It only picks how loud an `idle_prompt` is.
- An `idle_prompt` that nothing holds back, with `bg_other` nonzero, gives
  `NEEDS_LOOK`: a cyan dot and a cyan age, sorted between `ERROR` and `WORKING`.
  With nothing outstanding it goes to `NEEDS_INPUT` as before. A direct ask
  (`PermissionRequest`, `permission_prompt`, the elicitation types,
  `agent_needs_input`) goes to `NEEDS_INPUT` however much work is running,
  including from a row that is already cyan.
- A held `idle_prompt` released by `tick()` goes through the same check, so a
  subagent retiring while a workflow is still listed lands on cyan, not red.

**The safety valve is a timer.** Nothing announces the end of a workflow, so
`NEEDS_LOOK` cannot wait for proof that the work finished. After `look_s`
(default 300 s) it graduates to `NEEDS_INPUT`, exactly where the unsoftened
notification would have gone. That is why unknown task types are counted here
while the subagent count ignores them: a wrong guess here costs at most `look_s`,
and the subagent count has no backstop at all. It also means a workflow that runs
longer than `look_s` still ends in red. That is the known limit, and the trade
against a session that really is waiting on you sitting cyan indefinitely.

Graduation goes through `set_state()`, so the age restarts and the ladder's two
and ten minutes count from the moment the alarm begins. The rungs deliberately do
not reset the age. Graduation does, because time spent cyan was not time spent
waiting on a human, by this state's own definition.

Repeat `idle_prompt`s leave a cyan row where it is, the same rule the ladder
follows, or the timer would never run out. Any tool event, a prompt, or a `Stop`
takes the row out of `NEEDS_LOOK`. It is not in the attention family, so unlike a
red row it does not wait for the agent that raised it.

Additional per-session info:

- **Elapsed time in current state** (e.g. "waiting 4m"). Computed on host, sent as seconds.
- **Cost and context usage** from the statusline command, when available. See [claude-code-integration.md](claude-code-integration.md).
- **Last tool name**, for a one-word hint of what it is doing. Optional, phase 2.

## Host daemon internals

```
beacon_host/
  main.py          CLI entry: config, logging, signals, the main loop
  hook_server.py   HTTP on 127.0.0.1:47391: POST /event, POST /status, GET /health
  state.py         SessionStore: apply_event(), apply_status(), tick(), snapshot()
  statusline.py    Composes the text returned to the statusline hook
  serial_link.py   Opens the COM port, writes snapshots, reconnects on loss
  persist.py       Saves and restores the session store across daemon restarts
  capture.py       Redacts and appends hook payloads to JSONL, for fixtures
  config.py        TOML config: port, label overrides, thresholds, logging
```

Threading model: the HTTP server thread pushes events onto a queue. The main loop drains the queue, updates state, ticks staleness, and writes one line to serial if the snapshot changed or one second has passed (so the elapsed timers advance). Serial writes stay single-threaded.

Device discovery: `--port COMx` explicit, else auto-detect by USB VID/PID via pyserial's port listing, matching either board: the Nano ESP32 (0x2341:0x0070) or an RP2040 (0x2E8A:0x0003, which is the generic RP2040 pair rather than the Zero's own). This is the only board-specific part of the host. The protocol and everything behind it are identical for both builds, and the heartbeat's `board` field names the one that answered.

**The daemon will not share its port.** `HTTPServer` sets `allow_reuse_address`, and on Windows `SO_REUSEADDR` lets a *second* process bind an address another process is already listening on — unlike Linux, where it only skips the `TIME_WAIT` delay. So a second daemon started cleanly, the "another beacon-host running?" check never fired, and the two split hook events between them at random. That was easy to hit by accident, because the quick start asks you to run `beacon-host --dry-run -v` and by step 5 the scheduled task is already running. That step now says to stop the task first, and the failure is loud rather than silent either way.

The socket now refuses to be shared, which turns that silent split into a clear error. Two details make the strictness safe: the listening socket is closed on shutdown rather than at process exit, and the bind is retried for five seconds before giving up. A predecessor still exiting releases the port in well under a second, while a daemon that is genuinely running is still there at the end — so a fast restart succeeds and a real duplicate is still reported.

**Session state survives a restart.** A session parked on a prompt sends no hook events at all, so there is nothing to re-register it. Holding state only in memory meant that every restart — at logon, after a crash, or to free the COM port for a reflash — silently dropped every waiting session, and the display then under-reported until each one was next touched. Worse, the symptom is a short display, which the troubleshooting guide otherwise blames on missing hooks: the wrong trail entirely.

The store is written to `sessions.json` beside the log whenever the snapshot actually changes, throttled to once every five seconds, and again on a clean stop. Writes go to a temporary file and are then renamed, so an interrupted write cannot leave a truncated file that fails to load on every subsequent start.

Timestamps are absolute and are not rebased on load: a session that has been waiting three hours should still read three hours. The consequence is that a session that was *working* when the daemon went down comes back past its staleness threshold and shows amber, which is honest — from the daemon's side it has been silent that long — and the next tool call corrects it.

Nothing tells the daemon that a window was closed while it was down, because `SessionEnd` would have gone nowhere. A row untouched for longer than `restore_max_age_s` (default 24 h) is therefore treated as a ghost and dropped rather than restored. `--no-persist` turns the whole thing off, and `--dry-run` never persists, so debugging cannot disturb the real daemon's state.

**Ghosts are dropped on two more occasions.** A Windows Update restart killed a session with no `SessionEnd`. The daemon restored it at logon as though it were parked. It was 21 hours old at the next daemon restart, so it was restored again, and it stayed on the display for 45 hours until a restart finally found it over the cutoff. Two holes let that happen, and both are closed:

- **Across a reboot, nothing is restored.** No Claude Code process survives one, so if the machine booted after `sessions.json` was saved, every session in it is dead. The boot time is now minus `GetTickCount64`, which counts time asleep, so waking from sleep does not discard live sessions. Fast Startup is the known miss: its shutdown hibernates the kernel, so uptime carries on while every user process is killed.
- **The 24-hour cutoff also applies while the daemon runs.** `tick()` drops any session with no hook event for `restore_max_age_s`, whatever its state. Before this, the cutoff applied only at load, so a ghost lived as long as the daemon did and any restart inside the window renewed it. The age runs from the last event, not from `state_since`: a parked `wait` row keeps its age across repeat notifications, and those repeats are what prove it is alive.

The log rotates at 1 MB with three backups, so it never exceeds about 4 MB. At INFO it grows a few kilobytes a day, mostly start-up and reconnect lines.

Device handling assumes the link is never reliable. The board disappears on every reflash, Windows can move the COM number if the cable changes port, and the Arduino IDE's serial monitor will hold the port if it is open. Every send is best-effort, a failure just drops the link, and reconnection is attempted every two seconds. Port discovery falls back to USB VID/PID so a moved cable needs no config change.

Daemon lifecycle on Windows: `scripts/install-task.ps1` registers a Scheduled Task that starts it at logon with `pythonw.exe`, so there is no console window, and restarts it if it dies. A task rather than a service, because the daemon only matters while you are logged in and a task is far easier to inspect and remove. A Windows Service (for example through WinSW) was reconsidered after a restart failed, and rejected: the failure was a daemon started by hand, outside the task, and a service manager cannot stop a process it did not launch any more than a task can. A service would also run in session 0 as a system account, away from the per-user `%LOCALAPPDATA%` state and hook traffic, and need admin rights to install and remove. Restarts go through `scripts/restart-daemon.ps1`, which kills every beacon-host process however it was started, starts the task, and fails unless a daemon younger than the restart answers `/health`. A daemon that loses the port bind logs the PID of the one holding it, which it gets by asking that one's `/health`. `GET /health` reports the daemon's `pid`, whether the device is answering (`device`, true only when a heartbeat arrived within 15 s; `device_state` is `ok`, `absent` or `silent`) and the last heartbeat's counters (`heartbeat`), plus `sessions`, `events_received`, `last_event_age_s`, `uptime_s`, `rows`, which is what is currently on the display, and `bg`, which is why a row is *not* red. Answering "why does the screen say that" should not require a serial cable. `events_received` is the field that separates "hooks not installed" from a daemon or wiring fault, and the daemon also logs a warning if a minute passes with no events at all. `bg` does the same job for the other silent failure: a row held behind a background count looks exactly like a session that is genuinely busy, and working out which needed the persisted state file plus the session's own transcript. It carries the outstanding subagent count, the untracked-work count behind a `look` row (`other`), whether the turn had ended, whether an `idle_prompt` is being held, and how long ago the count was last confirmed — and it is empty unless a session has something outstanding. A tray icon is a possible later addition, not phase 1.

## Firmware internals

- Single sketch, Arduino IDE, same libraries as `env_monitoring` (Adafruit_GFX, Adafruit_ST7735) plus ArduinoJson.
- `Serial` (USB CDC) at 115200. Reads until newline, parses with an ArduinoJson 7 `JsonDocument`, which sizes itself on the heap; the old fixed-capacity `StaticJsonDocument` is gone from that library. A line longer than the 1024-byte buffer is discarded whole, remainder included, and counted in the heartbeat's `drop`.
- Repaints only changed *fields*, tracking what the header, each row, and the footer currently show. Measured on this panel over software SPI, a full-screen repaint cost about 900 ms, a full two-row repaint about 100 ms, and a field-level update of one row about 28 ms. Since the host resends a snapshot every second purely to advance timers, repainting everything would have left the device permanently mid-sweep, so this is not a premature optimisation. The sketch has since moved to hardware SPI at 24 MHz, which cut those figures by roughly an order of magnitude and needed no rewiring; the partial-update path is kept because the reasoning holds at any speed, and `USE_HARDWARE_SPI 0` reverts to bit-banging the same pins.
- **Nothing is cleared to background before being drawn.** Every varying field is a
  fixed width at a fixed x, drawn with an opaque text background so each glyph erases
  the cell it replaces. Right-aligned values are space-padded into their field rather
  than repositioned, so a value going from `9s` to `10s` does not move. Clearing a row
  first and then drawing over it produced a visible flash once a second, because the
  row sat blank for the tens of milliseconds software SPI needs. A row is cleared only
  when its background colour genuinely changes, which for a steady session is never.
- **All timer comparisons go through `elapsed(now, since, ms)`, which uses a signed difference.** See the timing note below; a plain unsigned `now - then` caused a real and confusing bug.
- Shows a "no host" screen if nothing arrives for 10 s, so an unplugged or dead daemon is obvious.
- Shows `no statusline data` in the footer when no cost or context has ever arrived. That data reaches the host only through the statusline hook, which is optional, so the strip was otherwise simply blank and read as a broken display rather than a feature that was never switched on.
- Shows a "no sessions" screen when the host is connected but reports nothing. These two failures have completely different causes and used to look identical: an empty screen. In practice "no sessions" means the Claude Code hooks were never installed, so the notice says so.
- Sends a heartbeat every 3 s. It is the host's only proof that the sketch is still running; see [the freeze below](#usb-writes-must-never-wait).
- Accepts local commands on the same serial line so the layout can be exercised without a host. A line starting with `{` is a protocol message; anything else is a command. `demo` loads a canned snapshot with running timers, and `hang` stops `loop()` on purpose to check that the watchdog reboots the board.
- Reports counters in its heartbeat: lines received, parse failures, dropped lines, lines it could not send, milliseconds since the last accepted message, the last render duration, and why the board last reset. These exist because a quiet host and a device that is dropping or failing to parse lines look identical from the outside, namely a screen reading "no host".
- **Never writes to `Serial` directly.** Output goes through `txLine()` into a queue, and `txPump()` hands the USB stack only as many bytes as it has room for.
- **The loop watchdog is on** (`enableLoopWDT()`, 5 s). A hung `loop()` reboots the board instead of freezing it.

### USB writes must never wait

The display froze on hours-old rows eight times in eight days. Only a power cycle fixed it. The panel looked healthy, but nothing on it moved: no footer page flip, no pulsing, no "no host". All three are driven from `loop()`, so `loop()` had stopped. The board stayed enumerated, Windows accepted every write, and `/health` said `"device": true`, because the host only checked that its port handle was open. One freeze lasted 7 h 26 min.

The cause is in the core, and it is the Nano's. On the Nano ESP32, `Serial` is TinyUSB's `USBCDC`. Its `write()` loops until every byte fits in a 64-byte FIFO, and that loop has no timeout: `setTxTimeoutMs()` bounds only the lock. When the PC stopped collecting from the port while DTR stayed asserted, the next heartbeat's `Serial.printf` spun forever. USB selective suspend is the likely trigger, since each freeze began with a single `WriteFile failed` on the host. Nothing rescued it, because the loop task on core 1 is not watched by the task watchdog by default, and the ST7735 keeps its last frame with no help from the MCU.

Three changes, all worth keeping:

- Output is queued and pumped out no faster than the FIFO drains. A stalled pipe drops whole lines, counted in `txdrop`. It no longer blocks.
- The RP2040 core is not exposed to the original fault: its `SerialUSB::write()` gives up after a second. Both builds queue anyway, because a second is still most of a frame and the queue costs nothing.
- The loop watchdog turns any future hang, whatever the cause, into a reboot after 5 s. The next heartbeat's `rst` shows it.
- The host acts on the heartbeat. It reports a port that is open but silent for 15 s as `silent` in `/health` and in the status line, and it logs a warning. A drop in the board's uptime is logged as a reboot, with the reason. Reopening the port does not revive a wedged board, so the host only reports it.

### A silent board is not a frozen one

Three sessions showed `beacon stuck: replug` for over two hours while the beacon on the desk was plainly alive: its rows aged and its counters advanced in real time. Two `/health` calls 137 s apart showed `age_s` climbing by exactly the wall clock and `up` frozen at the value it had had two hours earlier, so no heartbeat had arrived -- while `rows` changed between the two calls, so the daemon was sending snapshots the whole time and the board was drawing them. Only the return path was dead.

The asymmetry is in the firmware. Every outgoing line passes `hostAttached()`, which is TinyUSB's `tud_cdc_n_connected(0)`. Inbound data passes nothing: `loop()` drains `Serial.available()` and renders whatever arrives. So a false `hostAttached()` silences the board completely and costs it nothing else.

That flag is `tud_mounted() && !tud_suspended() && DTR`, three facts that can each go false without the pipe stopping -- a missed RESUME after a selective-suspend cycle leaves `suspended` set while data still flows, and a DTR that Windows drops is never re-asserted, because the daemon never reopens the port. It has been wrong before: the `if (Serial)` check it replaced was wrong in the other direction.

**Removing the `hostAttached()` checks does not fix this, and that is worth knowing before anyone tries.** It is the obvious move and it is useless: `USBCDC::write()` and `USBCDC::availableForWrite()` both test `tud_cdc_n_connected()` themselves and return 0 while it is false. No byte can leave the board by any route the sketch controls. Nor can the host cure it -- reopening the port was already shown not to work, and deliberately toggling DTR/RTS would be worse than useless, because the core watches those two lines for a four-step pattern that restarts the chip into its bootloader.

What the firmware *can* do is notice. Receiving snapshots while not one byte leaves the board is a flat contradiction, and it is the only evidence of this state anywhere on either side of the link. `txWatchdog()` holds it for 30 s -- long enough that a genuine unplug resolves itself, since with no host there is no inbound traffic either -- and then does what users were doing by hand: re-enumerates the device by rebooting it. The host already treats a reboot as an ordinary reconnect.

The first version watched `hostAttached()` instead of bytes, and missed the next episode entirely. The board rendered every snapshot for over five hours, across five daemon restarts, without sending one heartbeat and without once rebooting; a raw read of the port with the daemon stopped got zero bytes in 25 s. Either the flag read *true* the whole time over a FIFO that never drained -- `availableForWrite()` stuck at 0, lines queuing and then dropping -- or it flickered back to true more often than every 30 s, and each flicker restarted the count. Both leave the flag-based check blind, and bytes written covers both as well as the case it was built for, because a board with a host is never quiet: it queues a heartbeat every 3 s. So the timer runs while snapshots are arriving and nothing has been written, and any byte that leaves resets it.

The cure is invisible by the time anyone looks, so it is counted in memory that survives the software reset -- RTC memory on the ESP32, the watchdog's scratch registers on the RP2040, which has none -- and reported in every later heartbeat as `wedge`. A rise in it is logged by the host. The same memory keeps what the episode looked like, because the report above could not say which of the two it was: `wcause` is what the flag read at the moment of the reboot, and `wflip` how often it changed during the episode, so the next occurrence names itself -- a steady `det` is a stale flag, `att` a stopped FIFO, and a high `wflip` a link flapping under selective suspend. `aflip` counts how often the flag has changed at all since boot, so a link that is flapping but recovering can be seen before it sticks. The `wedge` serial command forces the flag false and `stall` stops the writes with the flag true, to test both paths on the bench as `hang` does for the loop watchdog.

### Timing: never subtract unsigned millis directly

The device alternated between the correct screen and "no host" roughly once a second. The cause was a stale timestamp, not the link.

`loop()` captured `now = millis()` at the top, then drained the serial buffer. Parsing a snapshot repaints the screen, which takes up to 900 ms, and `parseMessage()` stamps `lastMsgMs` when it finishes. So `lastMsgMs` ended up several hundred milliseconds *ahead* of `now`, and the staleness check `now - lastMsgMs > NO_HOST_MS` underflowed to about 4.3 billion. That is greater than every timeout, so the device painted "no host" directly over the frame it had just drawn correctly.

Two changes, both worth keeping:

- `loop()` reads serial first and takes `now` afterwards, so timestamps set during parsing are never in the future.
- Every timer comparison uses `elapsed(now, since, ms)`, which casts the difference to `int32_t`. That is wrap-safe across the 49-day `millis()` rollover and simply returns false if a timestamp is briefly ahead, rather than firing the timeout. The rollover would have caused the same failure once every seven weeks.

## Screen layout (160x128 landscape)

```
+----------------------------------------+
| BEACON      4 active          $4.20    |  header, 16 px
|----------------------------------------|
|############ env_monitoring     44s ####|  row 1, filled red, pulsing
|############ data-pipeline       5m ####|  row 2, filled red, static
| o session-beacon                 2m    |  row 3, blue dot
| o homelab                        7s    |  row 4, green dot
|                                        |
|                                        |
|----------------------------------------|
| ctx 41% [####......]          opus5    |  footer, alternates every 4 s
+----------------------------------------+
```

Six rows of 16 px fit between the header and the footer, using the default 6x8 GFX font at size 1.

**State is carried by colour, not by a word.** An earlier draft spelled the state out in each row, but the widest one, `NEEDS YOU`, needs 54 px, and a row only has 160 px to divide between the dot, a 16-character label, the state, and the age. That overcommits the row by eight pixels and the state text runs into the age. Dropping the word frees enough space that the label and the age can never collide.

| Element | x range | Notes |
|---|---|---|
| Featured marker | 0 to 1 | Present only on the session the footer describes |
| Dot | 3 to 9 | Filled circle in the state colour |
| Label | 13 to 109 | Up to 16 characters. The host shortens longer ones from the middle (`inventory..vice2`), so clones that differ only in a suffix stay distinct |
| Age | ends at 157 | Right-aligned, up to 4 characters |

That leaves 24 px of clear space between the longest label and the longest age.

Row colours:

| State | Dot | Row treatment |
|---|-----|---|
| `need` | none, the row itself is the signal | Filled edge to edge, alternating red-on-black and black-on-red twice a second |
| `held` | none, as `need` | Filled edge to edge in red, static. Drawn once and never repainted |
| `wait` | amber | Age also drawn amber. Identical to `stale`, deliberately |
| `look` | cyan | Age also drawn cyan. The age carries it because `work`'s blue is already an azure, too close for a 7 px dot alone |
| `work` | blue | Plain |
| `idle` | green | Plain |
| `stale` | amber | Age also drawn amber |
| `err` | magenta | Age also drawn magenta |
| `start` | grey | Plain |
| `end` | dim grey | Label drawn grey |

### The footer alternates

It carries two pages, four seconds each:

```
| ctx  54% [#####.....]         opus5    |   the featured session
| 5h   92% [#########.]       7d  28%    |   this account's usage
```

The context page describes **one** session, the one at `sel`, and that row carries a
two-pixel marker down its left edge so it is visible which. The marker takes the
label's colour, so it adapts to the state for free: white normally, grey on an ended
one. The exception is red fill, where the label is black. A black bar there read as
the fill starting a pixel late compared with the red row below, so on red it is
white instead. It stays put rather than appearing only
while the context page is up, because a marker blinking every four seconds would be
worse than a slightly imprecise one. The usage page is account-wide and belongs to no
row.

Both pages put their three fields at identical positions, so alternating does not
make anything jump: an eight-character value on the left, the same bar, an
eight-character value on the right. The bar is coloured by threshold either way,
so a five-hour window at 92% turns it red exactly as a nearly-full context window
does.

It only alternates when both pages have something to say. With no account figures
it parks on the session page, and with no session context it parks on the usage
page, so nothing ever blinks at a blank second page.

Rate limits arrive only with a statusline refresh, so the host drops them from the
snapshot after five minutes without one. A percentage from an hour ago is worse
than no percentage when the whole point is knowing where you stand now.

The pulse alternates between two readable states rather than flashing text in and out, so the row reads as a pulse instead of a flicker. Because it is driven by a local timer, the host never has to send frames for it.

Only `need` is repainted on the blink tick. A `held` row is the same fill held permanently in the phase `need` spends half its time in, so it is drawn once and then costs nothing per frame however many of them are on screen.

If more than six sessions are live, the host sorts the red rungs first, then `err`, then `look`, then `work`, then the rest, and the header's active count reveals the overflow. Sessions that have been waiting long enough to reach `wait` sort below `work`, so a row of parked sessions cannot push a working one off the display.

**Only changed regions are repainted.** A full repaint over software SPI is slow enough to be visible as a sweep, and the host resends a snapshot every second purely to advance the timers. The device keeps a record of what each row currently shows and compares the *formatted* age string rather than the raw seconds, so a row showing `14m` stays untouched for a full minute. In steady state a snapshot costs nothing to draw.

## Non-goals (for now)

- No Wi-Fi, no MQTT, no cloud. USB only.
- No input on the device (buttons). Interaction is via the PC.
- No Linux host support in phase 1, though nothing in the design is Windows-specific except the COM port naming and the hook command line.

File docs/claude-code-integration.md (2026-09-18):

# Claude Code integration

Everything the beacon knows comes from two Claude Code features: **hooks** and the **statusline command**. Both are configured in `~/.claude/settings.json` and apply to every session on the machine, which is exactly what we want.

Field names below have been checked against payloads captured on this machine, not just against the published schemas, and the two disagree. Reference: [hooks](https://code.claude.com/docs/en/hooks), [statusline](https://code.claude.com/docs/en/statusline).
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

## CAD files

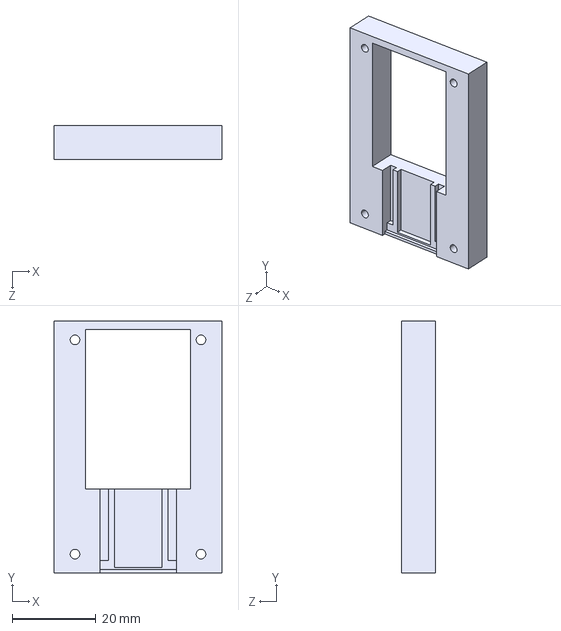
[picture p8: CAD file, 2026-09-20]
enclosure/mid-rp2040-v0.STEP
40.0 x 60.0 x 8.00 mm

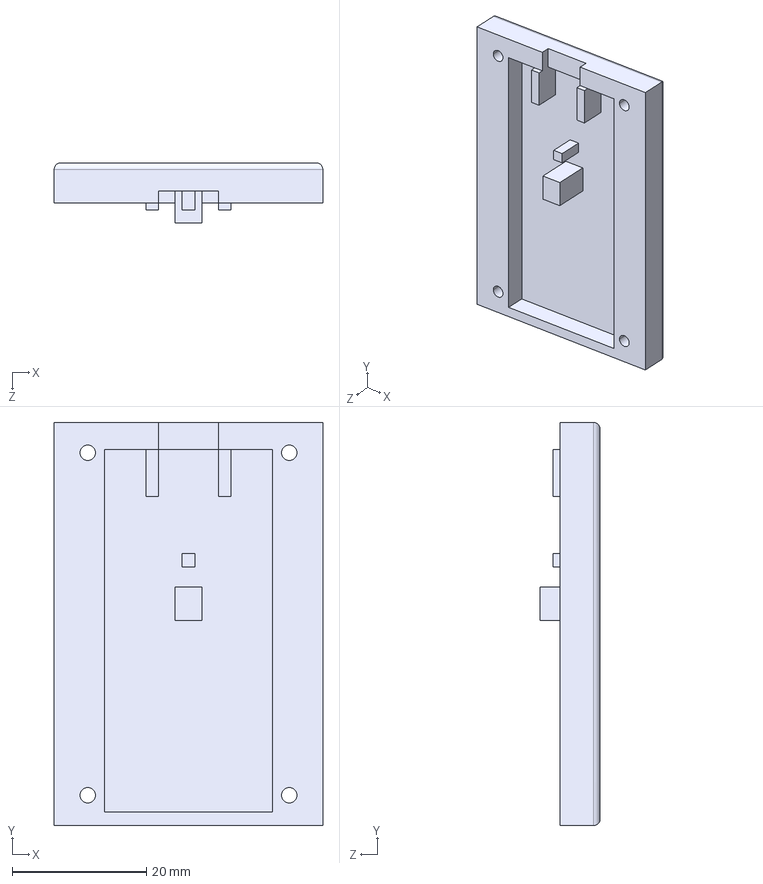
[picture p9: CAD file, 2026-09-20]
enclosure/back-rp2040-v0.STEP
40.0 x 60.0 x 9.00 mm

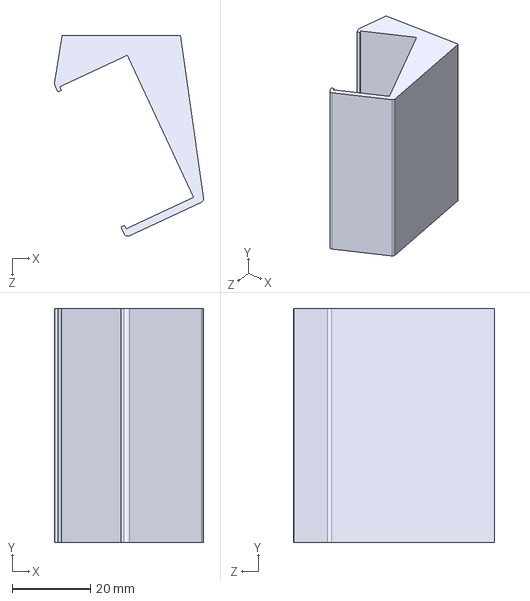
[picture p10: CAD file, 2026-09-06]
enclosure/25-degree-stand-v0.STEP
38.2 x 60.0 x 51.4 mm

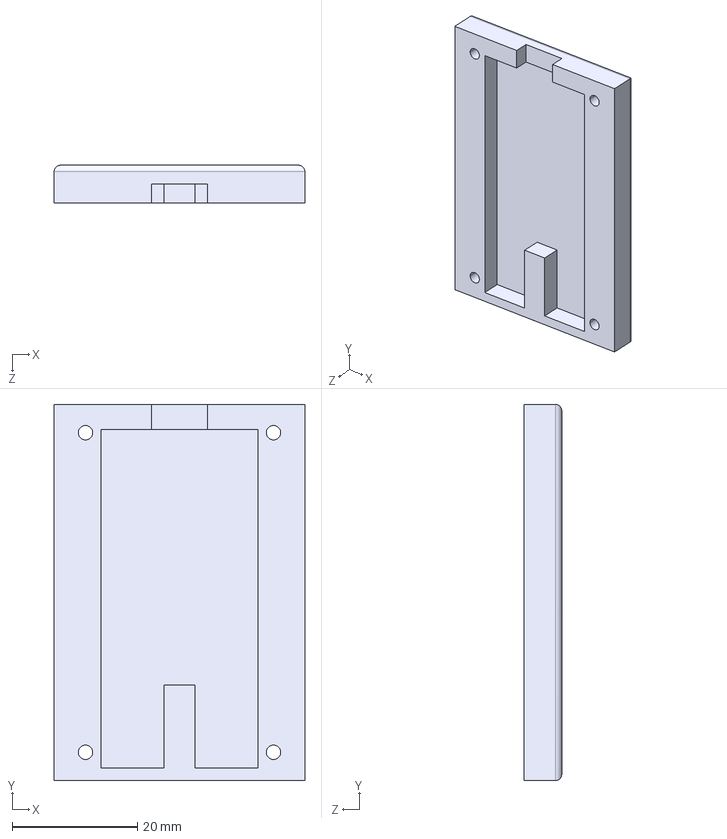
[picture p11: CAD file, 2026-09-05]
enclosure/back-v0.STEP
40.0 x 60.0 x 6.00 mm

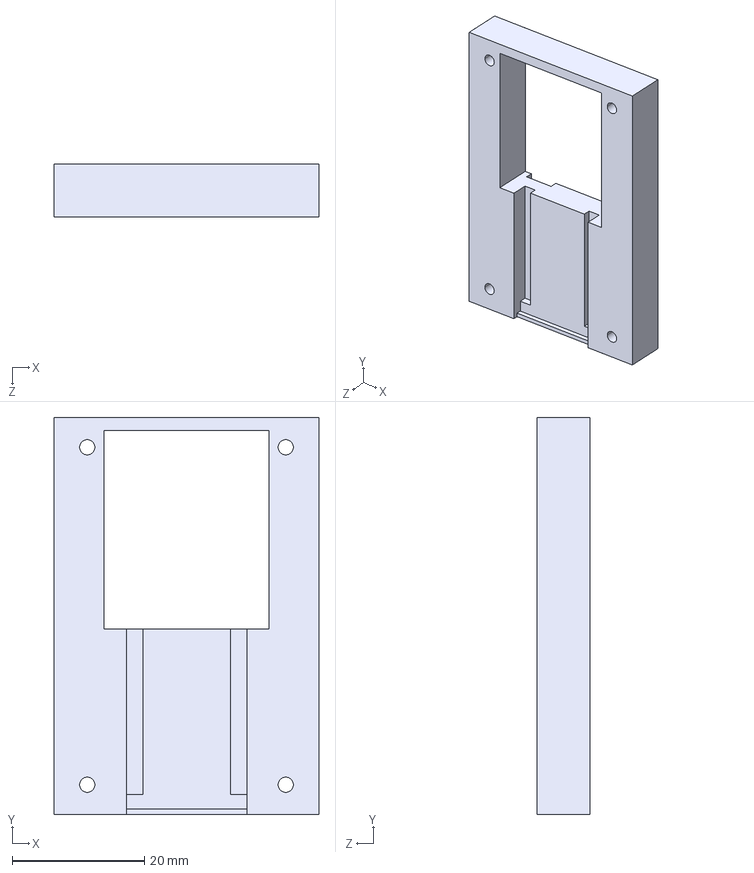
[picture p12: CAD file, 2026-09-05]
enclosure/mid-v0.STEP
40.0 x 60.0 x 8.00 mm

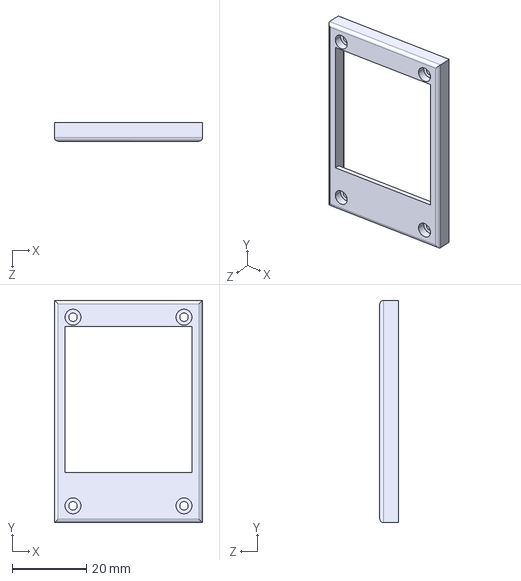
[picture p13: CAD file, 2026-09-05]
enclosure/front-v0.STEP
40.0 x 60.0 x 5.00 mm

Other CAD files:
enclosure/25-degree-stand-v0.3MF
enclosure/25-degree-stand-v0.SLDPRT
enclosure/back-rp2040-v0.3MF
enclosure/back-rp2040-v0.SLDPRT
enclosure/back-v0.3MF
enclosure/back-v0.SLDPRT
enclosure/front-v0.3MF
enclosure/front-v0.SLDPRT
enclosure/mid-rp2040-v0.3MF
enclosure/mid-rp2040-v0.SLDPRT
enclosure/mid-v0.3MF
enclosure/mid-v0.SLDPRT

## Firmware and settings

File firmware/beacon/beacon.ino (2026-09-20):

// Session Beacon firmware for Arduino Nano ESP32 + 1.8" ST7735 TFT.
//
// Reads newline-delimited JSON snapshots over USB serial (see docs/protocol.md)
// and renders them. No policy lives here: the host decides order, labels, and
// which session is featured. This sketch only draws.
//
// Board:     Arduino Nano ESP32 (Arduino ESP32 Boards package)
// Libraries: Adafruit GFX, Adafruit ST7735 and ST7789, ArduinoJson 7
//
// Serial input starting with '{' is treated as a protocol message. Anything
// else is a local command, so the display can be exercised without a host:
//
//   demo   load a canned snapshot and animate it
//   live   leave demo mode
//   hang   stop loop() on purpose, to check the watchdog reboots the board
//   wedge  pretend the host detached, to check the TX watchdog reboots it
//   stall  pretend the pipe stopped draining with the host still attached,
//          to check the TX watchdog reboots it from that side too
//   ?      command list

#include <SPI.h>
#if defined(ARDUINO_ARCH_RP2040)
#include <hardware/structs/watchdog.h>  // scratch registers; see the wedge counters
#else
#include <esp_system.h>
#include "tusb.h"   // tud_cdc_n_connected(); Serial is TinyUSB CDC on this board
#endif
#include <Adafruit_GFX.h>
#include <Adafruit_ST7735.h>
#include <ArduinoJson.h>

// ---- Display wiring ----
//
// The two builds share this panel and differ only in which pins carry it and
// which SPI peripheral drives them. See docs/hardware.md#wiring.
#if defined(ARDUINO_ARCH_RP2040)
// RP2040-Zero. These are the numbers printed on the board, which are GPIO
// numbers; the position numbers in pinout diagrams are a different scheme that
// collides with them. All eight wires are on the left edge, component side up
// with USB-C at the top.
#define BEACON_BOARD "rp2040-zero"
#define TFT_CS    28
#define TFT_RST   26
#define TFT_DC    27
#define TFT_MOSI  15   // SPI1 TX
#define TFT_SCLK  14   // SPI1 SCK
#define TFT_BUS   SPI1
#else
// Nano ESP32. Arduino pin names, never raw GPIO numbers, same as env_monitoring.
#define BEACON_BOARD "nano-esp32"
#define TFT_CS    D10
#define TFT_RST   D9
#define TFT_DC    D8
#define TFT_MOSI  D11
#define TFT_SCLK  D13
#define TFT_BUS   SPI
#endif

// Hardware SPI. On both boards the display is already wired to the pins its SPI
// peripheral drives: D11/D13 are the Nano's MOSI and SCK, and 15/14 are SPI1's
// on the RP2040-Zero, both confirmed in the variant's pins_arduino.h.
//
// The three-argument constructor selects the default peripheral, which is SPI0
// and therefore wrong on the RP2040-Zero, so that build names its bus. The
// five-argument form names MOSI and SCK and makes the library bit-bang them
// instead. Set USE_HARDWARE_SPI to 0 to go back, which is the whole revert.
#define USE_HARDWARE_SPI 1

// The library defaults to 32 MHz. That is optimistic for an ST7735S on jumper
// wires, and the failure is cosmetic but confusing: speckled pixels or a
// scrambled frame rather than a clean failure. 24 MHz is still roughly fifteen
// times faster than bit-banging. Lower this first if the picture is dirty.
static constexpr uint32_t SPI_HZ = 24000000;

#if USE_HARDWARE_SPI && defined(ARDUINO_ARCH_RP2040)
Adafruit_ST7735 tft = Adafruit_ST7735(&TFT_BUS, TFT_CS, TFT_DC, TFT_RST);
#elif USE_HARDWARE_SPI
Adafruit_ST7735 tft = Adafruit_ST7735(TFT_CS, TFT_DC, TFT_RST);
#else
Adafruit_ST7735 tft = Adafruit_ST7735(TFT_CS, TFT_DC, TFT_MOSI, TFT_SCLK, TFT_RST);
#endif

// ---- Panel colour order ----
//
// This panel is wired BGR, so the library's default for INITR_GREENTAB shows
// red and blue swapped. Confirmed on the bench with the colour chart in
// tft_smoketest. The env_monitoring display turned out to be BGR as well, so
// expect BGR from this part, but verify rather than assume: the check is free.
//
// setRotation() is the only thing that writes MADCTL, so overriding it once
// after setRotation() is enough. Any new setRotation() call must be followed
// by applyPanelColorOrder() again.
static constexpr uint8_t CMD_MADCTL  = 0x36;
static constexpr uint8_t MADCTL_MY   = 0x80;
static constexpr uint8_t MADCTL_MV   = 0x20;
static constexpr uint8_t MADCTL_BGR  = 0x08;  // clear this bit for RGB order

// What the library writes for INITR_GREENTAB at rotation 1, minus the BGR bit.
static constexpr uint8_t MADCTL_ROT1_RGB = MADCTL_MY | MADCTL_MV;

static void applyPanelColorOrder() {
  uint8_t v = MADCTL_ROT1_RGB;
  tft.sendCommand(CMD_MADCTL, &v, 1);
}

// ---- Constants ----
static constexpr const char* FW_VERSION = "0.3.0";
static constexpr uint8_t  PROTOCOL_V    = 1;
static constexpr uint32_t BAUD          = 115200;
static constexpr size_t   LINE_BUF      = 1024;
static constexpr uint32_t NO_HOST_MS    = 10000;
static constexpr uint32_t BLINK_MS      = 500;
static constexpr uint32_t HEARTBEAT_MS  = 3000;
static constexpr uint32_t FOOTER_PAGE_MS = 4000;  // footer alternation period
static constexpr uint8_t  MAX_ROWS      = 6;

static constexpr int16_t W = 160, H = 128;
static constexpr int16_t HEADER_H = 16, FOOTER_H = 16, ROW_H = 16;
static constexpr int16_t ROWS_Y = HEADER_H;
static constexpr int16_t FOOTER_Y = H - FOOTER_H;

// Row geometry. The default GFX font is 6x8 px at size 1.
//
// State is carried by the dot colour and, for the one state that matters, by
// filling the whole row. That frees the 54 px a spelled-out "NEEDS YOU" used
// to need, which is what made the label and the age collide.
//
//   dot 3..9 | label 13..109 (16 chars) | gap | age right-aligned to 157
static constexpr int16_t SEL_W      = 2;    // featured-row marker, x 0..1
static constexpr int16_t DOT_CX     = 6;
static constexpr int16_t DOT_R      = 3;
static constexpr int16_t LABEL_X    = 13;
static constexpr uint8_t LABEL_MAX  = 16;   // 16 * 6 = 96 px
static constexpr int16_t AGE_RIGHT  = 157;  // 4-char age starts at 133
static constexpr int16_t TEXT_DY    = 4;    // centres an 8 px glyph in a 16 px row

// Every varying field is a FIXED WIDTH, drawn at a FIXED x, with opaque text.
// Adafruit_GFX fills the whole 6x8 cell when a background colour is given, so
// each glyph erases what it replaces. Nothing is cleared to background first,
// which is what removes the flash on every update. Right-aligned values are
// space-padded into their field rather than moved, so the start never shifts.
static constexpr uint8_t AGE_W    = 4;
static constexpr int16_t AGE_X    = AGE_RIGHT - 6 * AGE_W;   // 133
static constexpr uint8_t COST_W   = 8;
static constexpr int16_t COST_X   = W - 4 - 6 * COST_W;      // 108
static constexpr int16_t COUNT_X  = 52;                      // "%2u active", 9 chars
static constexpr uint8_t MODEL_W  = 8;
static constexpr int16_t MODEL_X  = W - 4 - 6 * MODEL_W;     // 108
static constexpr int16_t BAR_X    = 56;
static constexpr int16_t BAR_W    = 44;

// ---- Colours (RGB565) ----
#define C_BG      ST77XX_BLACK
#define C_HEADER  0x000F   // dark blue
#define C_TEXT    ST77XX_WHITE
#define C_MUTED   0x7BEF   // light grey
#define C_GRID    0x4208   // dark grey
#define C_START   0x7BEF   // grey
#define C_WORK    0x04FF   // blue
#define C_NEED    ST77XX_RED
#define C_IDLE    ST77XX_GREEN
#define C_STALE   0xFD20   // amber, and see C_WAIT
#define C_ERR     0xF81F   // magenta
#define C_END     0x4208   // dim grey
// Deliberately the same amber as stale, not an oversight. "Busy but gone quiet"
// and "waiting on you for a while" ask a person for the same thing -- look at
// this one when you get a chance -- and in both the age is the informative
// part. They stay separate on the wire so the host, /health and the sort can
// tell them apart; only the pixels converge. Do not split this into a colour of
// its own without a reason the display itself can show.
#define C_WAIT    C_STALE
// An idle session that still has a workflow or background shell running. Not
// amber: `wait` and `stale` mean an ask has gone unanswered, and `look` means
// nothing is asking yet. The age is drawn cyan as well as the dot, because
// C_WORK is already an azure and a 7 px dot alone would read as `work`.
#define C_LOOK    0x07FF   // cyan

// ---- Snapshot model ----
struct Session {
  char id[9];
  char label[LABEL_MAX + 1];
  char state[6];
  char model[9];
  uint32_t age;
  int8_t ctx;        // -1 = unknown
};

struct Snapshot {
  bool valid = false;
  uint8_t n = 0;
  uint8_t count = 0;
  int8_t sel = -1;
  float cost = -1;
  int8_t rlH5 = -1;   // account usage, 5-hour window, percent. -1 = unknown
  int8_t rlD7 = -1;   // account usage, 7-day window, percent
  Session s[MAX_ROWS];
};

Snapshot snap;

// What is currently painted, so only changed regions are redrawn. A full
// repaint over software SPI takes long enough to be visible as a sweep, and
// the host resends a snapshot every second purely to advance the timers.
struct RowView {
  bool used = false;
  bool featured = false;
  char label[LABEL_MAX + 1] = "";
  char age[AGE_W + 1] = "";
  // Colours rather than the state name: they are what actually gets drawn, and
  // they already encode both the state and the blink phase.
  uint16_t bg = 0;
  uint16_t labelFg = 0;
  uint16_t ageFg = 0;
  uint16_t dot = 0;
};

struct HeaderView {
  bool valid = false;
  uint8_t n = 0;
  char cost[10] = "";
};

struct FooterView {
  bool valid = false;
  bool hint = false;   // showing the "nothing feeds this" message
  uint8_t page = 0;    // 0 = session context, 1 = account rate limits
  int8_t ctx = -2;
  int8_t h5 = -2;
  int8_t d7 = -2;
  char model[9] = "";
};

RowView   shownRows[MAX_ROWS];
HeaderView shownHeader;
FooterView shownFooter;

char lineBuf[LINE_BUF + 1];
size_t lineLen = 0;
// Set when a line outgrows the buffer, cleared at its newline. Without it the
// first LINE_BUF bytes were dropped and the *tail* was then treated as a fresh
// line: it does not start with '{', so it reached handleCommand() and printed
// the help text. An over-long line is discarded whole, as the protocol says.
bool lineOverflow = false;
uint32_t lastMsgMs = 0;
uint32_t lastBlinkMs = 0;
uint32_t lastHbMs = 0;
bool blinkOn = true;
uint8_t footerPage = 0;
uint32_t lastFooterFlipMs = 0;
bool showingNoHost = false;
bool shownEmpty = false;
bool demoMode = false;

// Receive counters, reported in the heartbeat. Without these, a host that
// has gone quiet and a device that is dropping or failing to parse lines
// look identical from the outside: a screen that says 'no host'.
uint32_t rxLines = 0;    // complete lines seen
uint32_t rxBad = 0;      // lines that failed to parse as JSON
uint32_t rxDropped = 0;  // lines abandoned for exceeding the buffer

// ---- Outbound serial ----
//
// Nothing in this sketch may call Serial.print*() or Serial.write() directly.
// On the ESP32 core Serial is TinyUSB's USBCDC, whose write() loops until every
// byte is in a 64-byte FIFO and has no timeout: setTxTimeoutMs() bounds only the
// lock, not the wait. If the PC stops collecting while DTR is still asserted,
// as a suspended USB port does, the write spins forever and loop() with it. The
// panel keeps its last frame, so the board looked alive but frozen for hours,
// eight times in eight days, until someone power-cycled it.
//
// The RP2040 core's SerialUSB::write() gives up after a second instead, so it
// cannot hang the sketch outright. A second is still most of a frame, and the
// queue costs nothing, so both builds go through it.
//
// So lines are queued here and txPump() hands the USB stack only as many bytes
// as it has room for. A stalled pipe fills the queue, and further lines are
// dropped whole and counted in the heartbeat's `txdrop`, rather than blocking.
static constexpr size_t TX_BUF = 512;
char txBuf[TX_BUF];
size_t txHead = 0;       // next byte to send
size_t txTail = 0;       // one past the last queued byte
uint32_t txDropped = 0;  // lines lost to a stalled pipe with a host attached

// Whether a host holds the port. This is the check write() itself makes. Do not
// use `if (Serial)` instead: that reads a separate flag which a DTR/RTS pattern
// detector updates only in its idle state, and it stayed false for the daemon's
// connection, so every heartbeat was discarded and the host reported a healthy
// board as stuck.
//
// It is not a sign of life either, and it cannot be made into one. This flag is
// `tud_mounted() && !tud_suspended() && DTR`, and it has been seen false on a
// link that was still delivering snapshots: the board rendered every frame it
// was sent while no heartbeat left it for over two hours. Do not answer that by
// dropping the checks below, which is the obvious move and does nothing:
// USBCDC::write() and availableForWrite() test the same flag themselves and
// both return 0 while it is false, so no byte can leave this board by any route
// the sketch controls. txWatchdog() cures it instead, by rebooting.
static bool forceDetached = false;  // `wedge` command; bench test only
static bool forceStalled = false;   // `stall` command; bench test only
#if defined(ARDUINO_ARCH_RP2040)
// SerialUSB::operator bool() is tud_cdc_connected(), the same predicate the
// ESP32 build spells out, and the same one its write() and availableForWrite()
// consult. The warning below about `if (Serial)` is about the *ESP32* core's
// separate flag; it does not apply here.
static bool hostAttached() { return (bool)Serial && !forceDetached; }
#else
static bool hostAttached() { return tud_cdc_n_connected(0) && !forceDetached; }
#endif

// Set whenever a byte actually leaves, and consumed by txWatchdog(). This, not
// hostAttached(), is what the watchdog trusts: see the note there.
static bool txProgressed = false;

static void txLine(const char* s) {
  // No host holding the port: nothing will read it, and counting these would
  // drown the stalls `txdrop` exists to report.
  if (!hostAttached()) return;
  const size_t n = strlen(s);
  if (txHead == txTail) txHead = txTail = 0;
  if (TX_BUF - txTail < n + 1 && txHead > 0) {
    memmove(txBuf, txBuf + txHead, txTail - txHead);
    txTail -= txHead;
    txHead = 0;
  }
  if (TX_BUF - txTail < n + 1) { txDropped++; return; }  // whole or not at all
  memcpy(txBuf + txTail, s, n);
  txTail += n;
  txBuf[txTail++] = '\n';
}

static void txPump() {
  if (txHead == txTail) return;
  if (!hostAttached()) { txHead = txTail = 0; return; }
  const int room = forceStalled ? 0 : Serial.availableForWrite();
  if (room <= 0) return;
  size_t n = txTail - txHead;
  if (n > (size_t)room) n = (size_t)room;
  // Never more than the free space, so write() cannot reach its waiting loop.
  const size_t sent = Serial.write((const uint8_t*)(txBuf + txHead), n);
  txHead += sent;
  if (sent) txProgressed = true;
}

// ---- Counters that outlive a reboot ----
// These four words have to outlive the reboot that writes them, which rules out
// ordinary variables: .bss and .data are re-initialised on every boot, software
// resets included.
//
// ESP32: RTC_NOINIT_ATTR, not RTC_DATA_ATTR. The latter is re-initialised on a
// software restart, which is precisely the event being counted, so the count
// would always read 0.
//
// RP2040: there is no RTC memory, but the watchdog's scratch registers survive
// a watchdog reboot, which is what rp2040.reboot() performs. Registers 4 to 7
// are spoken for -- the SDK's watchdog_reboot() leaves the bootrom a magic
// number and an entry point in them -- so this uses 0 to 3.
//
// On both, the price is that the words are undefined after a power-on reset
// rather than zeroed, hence the cookie and setup()'s check.
static constexpr uint32_t TX_WEDGE_MS = 30000;
static constexpr uint32_t WEDGE_COOKIE = 0x57454448;  // bumped with the layout below
enum : uint32_t { WEDGE_NONE = 0, WEDGE_DETACHED = 1, WEDGE_ATTACHED = 2 };
enum : uint8_t { W_COOKIE = 0, W_CURES = 1, W_CAUSE = 2, W_FLIPS = 3 };

#if defined(ARDUINO_ARCH_RP2040)
static inline uint32_t wedgeGet(uint8_t i)             { return watchdog_hw->scratch[i]; }
static inline void     wedgeSet(uint8_t i, uint32_t v) { watchdog_hw->scratch[i] = v; }
#else
RTC_NOINIT_ATTR uint32_t wedgeSlot[4];
static inline uint32_t wedgeGet(uint8_t i)             { return wedgeSlot[i]; }
static inline void     wedgeSet(uint8_t i, uint32_t v) { wedgeSlot[i] = v; }
#endif

// ---- Platform ----
//
// The three things the two cores spell differently: why the board last reset,
// how to reboot it, and the loop watchdog. Everything else in this sketch is
// Arduino or library API.

// Why this boot happened, for the heartbeat. A watchdog reason here is the
// watchdog below having rescued a hung loop(); `sw` is txWatchdog()'s cure.
#if defined(ARDUINO_ARCH_RP2040)
// The RP2040 has one reset path for both, so the sketch has to label its own.
// rp2040.reboot() is watchdog_reboot(0, 0, 10), and with a zero entry point
// that is indistinguishable from the loop watchdog timing out: both set the
// watchdog's reason bit and leave the SDK's scratch[4] clear, so
// getResetReason() answers WDT_RESET for each. Verified on the board, where
// txWatchdog()'s cure reported `rst` as `wdt`.
//
// So a cure marks itself, in the high bit of the word that already carries its
// cause. The mark is read and cleared once, at boot, before anything else can
// reboot the board. A reset with no mark and the watchdog's reason bit really
// was the loop watchdog -- or the UF2 bootloader, which also reboots this way,
// so `wdt` is expected on the first boot after flashing.
static constexpr uint32_t WEDGE_SW_MARK = 0x80000000u;

static void markOwnRestart() { wedgeSet(W_CAUSE, wedgeGet(W_CAUSE) | WEDGE_SW_MARK); }

static const char* resetReason() {
  const bool ours = wedgeGet(W_CAUSE) & WEDGE_SW_MARK;
  if (ours) wedgeSet(W_CAUSE, wedgeGet(W_CAUSE) & ~WEDGE_SW_MARK);
  switch (rp2040.getResetReason()) {
    case RP2040::PWRON_RESET:    return "power";
    case RP2040::SOFT_RESET:     return "sw";
    case RP2040::WDT_RESET:      return ours ? "sw" : "wdt";
    case RP2040::RUN_PIN_RESET:  return "run_pin";
    case RP2040::DEBUG_RESET:    return "debug";
    case RP2040::GLITCH_RESET:   return "glitch";
    case RP2040::BROWNOUT_RESET: return "brownout";
    default:                     return "other";
  }
}

static void restartBoard() {
  markOwnRestart();
  rp2040.reboot();
}
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
void loop() {
  // Read serial BEFORE taking the time. Parsing a snapshot repaints the
  // screen, which is slow, and parseMessage() stamps lastMsgMs afterwards.
  // A `now` captured up here would then be behind lastMsgMs and underflow
  // the staleness check, painting "no host" straight over the frame that
  // had just been drawn correctly.
  while (Serial.available()) {
    char c = (char)Serial.read();
    if (c == '\n' || c == '\r') {
      if (lineOverflow) {
        lineOverflow = false;   // the rest of an abandoned line, not a command
      } else if (lineLen) {
        lineBuf[lineLen] = 0;
        rxLines++;
        if (lineBuf[0] == '{') parseMessage(lineBuf);
        else                   handleCommand(lineBuf);
      }
      lineLen = 0;
    } else if (lineOverflow) {
      // Still inside the over-long line; keep discarding to its newline.
    } else if (lineLen < LINE_BUF) {
      lineBuf[lineLen++] = c;
    } else {
      lineLen = 0;
      lineOverflow = true;
      rxDropped++;  // line longer than the buffer; abandoned whole
    }
  }

  const uint32_t now = millis();

  // Pulse rows that need attention.
  if (elapsed(now, lastBlinkMs, BLINK_MS)) {
    lastBlinkMs = now;
    blinkOn = !blinkOn;
    if (snap.valid && !showingNoHost) {
      for (uint8_t i = 0; i < snap.count; i++)
        if (isPulsing(snap.s[i].state)) drawRow(i);
    }
  }

  // Alternate the footer between session context and account usage.
  if (elapsed(now, lastFooterFlipMs, FOOTER_PAGE_MS)) {
    lastFooterFlipMs = now;
    footerPage ^= 1;
    if (snap.valid && !showingNoHost) drawFooter();
  }

  // Demo mode advances its own timers so the layout can be watched live.
  if (demoMode && elapsed(now, lastMsgMs, 1000)) {
    lastMsgMs = now;
    for (uint8_t i = 0; i < snap.count; i++) snap.s[i].age++;
    render();
  }

  if (!demoMode && !showingNoHost && elapsed(now, lastMsgMs, NO_HOST_MS)) {
    drawNoHost();
    showingNoHost = true;
  }

  if (elapsed(now, lastHbMs, HEARTBEAT_MS)) {
    lastHbMs = now;
    int32_t since = (int32_t)(now - lastMsgMs);
    if (since < 0) since = 0;
    char hb[320];
    snprintf(hb, sizeof hb,
             "{\"t\":\"hb\",\"fw\":\"%s\",\"board\":\"%s\",\"up\":%lu,\"rx\":%lu,\"bad\":%lu,\"drop\":%lu,\"txdrop\":%lu,\"aflip\":%lu,\"wedge\":%lu,\"wcause\":\"%s\",\"wflip\":%lu,\"since\":%ld,\"render\":%lu,\"spi\":\"%s\",\"rst\":\"%s\"}",
             FW_VERSION, BEACON_BOARD, (unsigned long)(now / 1000),
             (unsigned long)rxLines, (unsigned long)rxBad,
             (unsigned long)rxDropped, (unsigned long)txDropped,
             (unsigned long)attachFlips, (unsigned long)wedgeGet(W_CURES),
             wedgeCauseName(), (unsigned long)wedgeGet(W_FLIPS), (long)since,
             (unsigned long)lastRenderMs,
#if USE_HARDWARE_SPI
             "hw",
#else
             "sw",
#endif
             bootReason);
    txLine(hb);
  }

  txWatchdog(now);
  txPump();
  watchdogFeed();  // nothing above may block for seconds; see watchdogBegin()
}

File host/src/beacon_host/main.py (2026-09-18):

"""beacon-host entry point.

    uv run beacon-host                      # config.local.toml, auto-detect port
    uv run beacon-host --port COM4 -v       # explicit port, debug logging
    uv run beacon-host --dry-run            # print snapshots instead of serial

Main loop: drain the hook queue, update state, age it, and push a snapshot to
the device when something changed or a second has passed.
"""

from __future__ import annotations

import argparse
import contextlib
import http.client
import json
import logging
import logging.handlers
import queue
import signal
import sys
import time
import urllib.request
from pathlib import Path

from . import hook_server, persist, procwatch
from .capture import Capture
from .config import Config, default_config_path, default_state_path
from .serial_link import SerialLink
from .state import SessionStore

log = logging.getLogger("beacon_host")

TICK_S = 0.05        # main loop granularity
PUSH_EVERY_S = 1.0   # resend at least this often so on-device timers advance
SAVE_EVERY_S = 5.0   # floor on how often session state is written to disk
BIND_RETRY_S = 5.0   # how long to wait out a predecessor still shutting down
LIVENESS_EVERY_S = 30.0  # how often each session's process is checked


def parse_args(argv: list[str] | None = None) -> argparse.Namespace:
    ap = argparse.ArgumentParser(prog="beacon-host")
    ap.add_argument("--config", help="TOML config path (default: config.local.toml)")
    ap.add_argument("--port", help="COM port (default: auto-detect Nano ESP32 by VID/PID)")
    ap.add_argument("--http-port", type=int)
    ap.add_argument("--stale-after", type=float, help="seconds before a busy session goes stale")
    ap.add_argument("--log-file")
    ap.add_argument("--capture", metavar="FILE",
                    help="append redacted hook payloads to FILE as JSONL, "
                         "for building test fixtures")
    ap.add_argument("--no-persist", action="store_true",
                    help="do not save or restore session state across restarts")
    ap.add_argument("-v", "--verbose", action="store_true", help="debug logging")
    ap.add_argument("--dry-run", action="store_true",
                    help="print snapshots instead of using serial")
    return ap.parse_args(argv)


def build_config(args: argparse.Namespace) -> Config:
    cfg = Config.load(args.config or default_config_path())
    if args.port:
        cfg.port = args.port
    if args.http_port:
        cfg.http_port = args.http_port
    if args.stale_after:
        cfg.stale_after_s = args.stale_after
    if args.log_file:
        cfg.log_file = args.log_file
    if args.verbose:
        cfg.log_level = "DEBUG"
    return cfg


def setup_logging(cfg: Config) -> None:
    handlers: list[logging.Handler] = [logging.StreamHandler(sys.stderr)]
    problem = None
    if cfg.log_file:
        # Rotating, because this runs unattended at login and nobody prunes it.
        # Create the directory: the handler will not, and a missing one takes
        # the whole daemon down at startup over a log file, which is absurd.
        try:
            Path(cfg.log_file).parent.mkdir(parents=True, exist_ok=True)
            handlers.append(
                logging.handlers.RotatingFileHandler(
                    cfg.log_file, maxBytes=1_000_000, backupCount=3, encoding="utf-8"
                )
            )
        except OSError as e:
            problem = f"file logging disabled, cannot use {cfg.log_file}: {e}"
    logging.basicConfig(
        level=cfg.log_level.upper(),
        format="%(asctime)s %(levelname)-7s %(name)s: %(message)s",
        handlers=handlers,
        force=True,
    )
    if problem:
        logging.getLogger("beacon_host").warning(problem)


def describe_port_holder(port: int) -> str:
    """Say who holds the HTTP port, for the error logged when the bind fails.

    Asking the holder beats asking the OS: if it answers /health it is a
    beacon-host and reports its own PID, which is the one fact needed to clear
    it. The case that forced this was a daemon started by hand with
    Start-Process: the Scheduled Task did not own it, so Stop-ScheduledTask
    left it running and the task's fresh copy died here with nothing in the
    log to say which process to look for.
    """
    try:
        with urllib.request.urlopen(f"http://127.0.0.1:{port}/health", timeout=1) as r:
            h = json.loads(r.read())
    except (OSError, http.client.HTTPException, ValueError):
        # URLError, a reset and a timeout are OSError; HTTPException is a
        # listener that does not speak HTTP; ValueError is a body that is not
        # JSON. Whichever it is, the holder is not a beacon-host.
        return "Something that is not beacon-host holds it."
    pid = h.get("pid", "?") if isinstance(h, dict) else "?"
    up = h.get("uptime_s", "?") if isinstance(h, dict) else "?"
    return (f"beacon-host PID {pid} already holds it (up {up}s). If the "
            "Scheduled Task did not start that one, stopping the task will not "
            "stop it: use scripts/restart-daemon.ps1.")
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

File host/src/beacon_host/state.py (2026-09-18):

"""Session state machine. Pure logic, no I/O, so it is unit-testable with fixtures.

See docs/architecture.md for the state diagram and docs/protocol.md for the
snapshot shape produced by SessionStore.snapshot().
"""

from __future__ import annotations

import os
from dataclasses import dataclass, field
from enum import StrEnum
from pathlib import Path
from typing import Any


class State(StrEnum):
    STARTING = "start"
    WORKING = "work"
    NEEDS_INPUT = "need"
    NEEDS_HELD = "held"
    NEEDS_LOOK = "look"
    WAITING = "wait"
    ERROR = "err"
    IDLE = "idle"
    STALE = "stale"
    ENDED = "end"


# The three rungs a session waiting on a human descends through, loudest first.
# Entering the family starts the ladder; re-entering it while already inside
# does not, or a prompt that re-notifies would pulse forever.
ATTENTION_STATES = (State.NEEDS_INPUT, State.NEEDS_HELD, State.WAITING)


# Display priority: lower sorts first.
#
# WAITING sits *below* WORKING, next to STALE, even though it still wants a
# human. It renders identically to STALE and it is the state sessions left idle
# on purpose settle into, so ranking it with the alarm states would park them in
# the top rows permanently and push actively working sessions off a six-row
# display. That is the noise the ladder exists to remove, not to relocate.
#
# NEEDS_LOOK sits just above WORKING: worth surfacing over a session that is
# plainly busy, never competing with a real block or an error.
PRIORITY = {
    State.NEEDS_INPUT: 0,
    State.NEEDS_HELD: 1,
    State.ERROR: 2,
    State.NEEDS_LOOK: 3,
    State.WORKING: 4,
    State.WAITING: 5,
    State.STALE: 6,
    State.STARTING: 7,
    State.IDLE: 8,
    State.ENDED: 9,
}

# Notification types that mean a human has to do something. Taken from the
# documented `notification_type` values; the rest are informational.
ATTENTION_NOTIFICATIONS = {
    "permission_prompt",
    "idle_prompt",
    "elicitation_dialog",
    "elicitation_url_dialog",
    "agent_needs_input",
}


@dataclass
class Session:
    session_id: str
    cwd: str
    label: str
    state: State = State.STARTING
    state_since: float = 0.0
    last_event: float = 0.0
    last_tool: str = ""
    model: str = ""
    cost_usd: float | None = None
    ctx_pct: int | None = None
    permission_mode: str = ""
    error_type: str = ""
    bg_tasks: int = 0
    # Background work the beacon cannot retire -- a workflow, a background shell,
    # a teammate -- as listed by the last Stop or SubagentStop. It only decides
    # how loud an idle_prompt is (NEEDS_LOOK rather than NEEDS_INPUT) and never
    # whether the row is WORKING; that stays `bg_tasks`' job alone.
    bg_other: int = 0
    # Which agent raised the attention this session is currently showing. "" is
    # the main thread. A subagent's hook events carry the *parent's* session_id,
    # so without this a subagent's tool call answers a prompt it never saw.
    attn_agent: str = ""
    # When the background count was last confirmed by a payload. A running
    # subagent emits hook events constantly, so silence means it is stale.
    bg_seen: float = 0.0
    # The turn ended while background work was still outstanding, so the session
    # is waiting on the machine and not yet on a person.
    turn_over: bool = False
    # An `idle_prompt` that arrived while background work was outstanding. Held
    # rather than dropped: Claude Code sent exactly *one* for the idle period
    # that turned this up, so a swallowed notification is a row that never goes
    # red at all. tick() releases it when the count retires.
    idle_held: bool = False
    idle_held_agent: str = ""
    # The Claude Code process behind the session, found by the daemon from the
    # hook's own TCP connection (procwatch.py); 0 if it could not be. Keyed by
    # creation time too, because Windows recycles PIDs.
    pid: int = 0
    pid_created: float = 0.0

    def set_state(self, new: State, now: float) -> None:
        if new != self.state:
            self.state = new
            self.state_since = now
        self.last_event = now
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

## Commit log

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2026-09-04 Add TFT smoke test sketch and bring-up procedure
    Standalone sketch to verify the ST7735S wiring before beacon.ino exists.
    Checks colour order, panel offsets, rotation, and font metrics, then draws a
    mock of the beacon layout and echoes serial input to the screen.
    Corrects two points in hardware.md against env_monitoring's own reference:
    current draw is ~30 mA, and INITR_GREENTAB is required for the ST7735S
    variant rather than one option among three. Adds a bring-up table mapping
    each smoke-test step to what a failure means.
    [tft_smoketest.ino]
2026-09-04 Add interactive colour diagnostic to TFT smoke test
    Wiring, geometry, offsets and text all check out on the bench, but red and
    green appear swapped. That is not what the controller's colour-order flag
    does: it swaps red and blue only. Rather than guess, the smoke test now
    draws six patches whose appearance differs under every channel permutation,
    so one look identifies the actual mapping.
    The sketch also drops into a command loop so the panel colour-order register
    can be toggled or set raw without reflashing, with a reset back to the
    library default when an experiment goes wrong.
    [tft_smoketest.ino]
2026-09-04 Correct panel colour order: this ST7735S unit is BGR-wired
    Bench testing identified a red/blue swap, which is the controller's
    colour-order flag. Both sketches now clear the BGR bit in MADCTL after
    setRotation, so every ST77XX constant and raw hex colour behaves as
    documented and no other code needs to know.
    Notable: the otherwise identical display in env_monitoring is RGB and needs
    no such fix, despite the same product listing. Recorded in hardware.md and
    CLAUDE.md so colour order gets checked per unit rather than assumed, and so
    the register write does not get tidied away later.
    [beacon.ino, tft_smoketest.ino]
2026-09-04 Rework row layout and render only changed regions
    The row overcommitted its 160 px: dot, 14-char label, a spelled-out state,
    and an age need 168 px, so 'NEEDS YOU' ran into the elapsed time. Dropping
    the state word frees 54 px and leaves a 24 px gap between the longest label
    and the longest age, with the label cap raised to 16 chars so repo names fit.
    State now reads as colour. The one state that matters fills its row edge to
    edge and pulses between red-on-black and black-on-red, both readable, so it
    reads as a pulse rather than text flashing in and out. That is far more
    glanceable across a desk than a 6 px word.
    Rendering now repaints only what changed, comparing the formatted age string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
    [beacon.ino, state.py, tft_smoketest.ino]
2026-09-04 Verify firmware builds, document headless build, flash to COM4
    Compiling caught a real defect: LINE_MAX collides with a POSIX macro from
    limits.h and failed the build. Renamed to LINE_BUF.
    Also verified the colour-order constant against the installed library source
    rather than from memory. Adafruit_ST7735::setRotation writes MY|MV|BGR for
    GREENTAB at rotation 1, and ST7735_MADCTL_BGR is 0x08, so clearing that bit
    gives exactly the 0xA0 the firmware now writes.
    Records the arduino-cli path bundled in the Arduino IDE install so firmware
    can be built and flashed without opening the GUI, and corrects the example
    port to COM4, which is where the board actually enumerates.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
    [beacon.ino]
2026-09-04 Reconcile host state machine with the published hook schema
    Verified the hook and statusline field names against the docs rather than
    memory, and several assumptions were wrong or incomplete.
    Corrections:
    - SessionStart carries session_start_reason and SessionEnd carries
    session_end_reason. There is no 'source' field.
    - agent_id and agent_type are present inside subagents, so subagent activity
    is distinguishable from the parent's. An earlier note said otherwise.
    - The statusline context fallback used invented field names. It now uses
    total_input_tokens, total_output_tokens and context_window_size, which
    matters because used_percentage is null early in a session and after a
    compact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
    [beacon.ino, state.py, test_state.py]
2026-09-04 Build out the host daemon; forward hooks with curl, not Python
    Answers the practical-use question with a measurement. The daemon stays
    Python, where startup cost is irrelevant and pyserial is mature. The
    forwarder does not: it runs on every tool call in every session, and there
    process startup is the whole cost.
    Posting one event, median of 20:
    curl.exe from System32 15.6 ms
    Python, system 99.1 ms
    Python, project venv 121.9 ms
    curl ships with Windows, so hook commands no longer depend on which Python is
    on PATH, need no venv activation, and need no quoting. The statusline hook is
    curl too: it POSTs the payload and the daemon returns the line to print in the
    respo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
    [config.py, hook_server.py, main.py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]
2026-09-04 Fix the blank-display trap: install hooks, name the config, say why
    The daemon was working the whole time. Claude Code was never calling it,
    because the hooks had not been added to settings.json, and the failure looked
    identical to a hardware fault: a connected device showing nothing.
    Three changes so this cannot happen quietly again.
    scripts/install-hooks.ps1 does the settings.json merge that was previously a
    manual instruction. It backs up first, is idempotent, preserves existing
    settings, validates the JSON before writing, and leaves the status line alone
    unless asked. Hooks load at session start, so it says to restart sessions.
    The firmware now distinguishes 'no host' from 'no session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
    [beacon.ino, config.py, hook_server.py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]
2026-09-04 Fix unsigned millis underflow that painted 'no host' over every frame
    The display alternated between the correct screen and 'no host' about once a
    second. The link was fine in both directions the whole time.
    loop() captured now = millis() at the top, then drained serial. Parsing a
    snapshot repaints the screen, which measures up to 900 ms over software SPI,
    and parseMessage() stamps lastMsgMs when it finishes. lastMsgMs therefore
    ended up several hundred milliseconds ahead of now, and the staleness check
    'now - lastMsgMs > NO_HOST_MS' underflowed to about 4.3 billion. That beats
    every timeout, so the device painted 'no host' straight over the frame it had
    just drawn correctly.
    Two fixes. lo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
    [beacon.ino]
2026-09-04 Stop the once-a-second flash: draw fields in place, never clear first
    Each row was filled with its background colour and then redrawn. Software SPI
    needs tens of milliseconds for that, so the row sat visibly blank every time
    the age string ticked, once a second.
    Every varying field is now a fixed width at a fixed x, drawn with an opaque
    text background so each glyph erases the cell it replaces. Right-aligned
    values are space-padded into their field instead of being repositioned, so
    '9s' becoming '10s' no longer shifts the start of the field and leaves a
    stale character behind. A row is cleared only when its background colour
    actually changes, which for a steady session never happens. The sa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
    [beacon.ino]
2026-09-04 Drive the TFT over hardware SPI instead of bit-banging
    The sketch was bit-banging D11 and D13, which the variant header defines as
    this board's MOSI and SCK. The display was already wired to the pins the SPI
    peripheral drives, so this is a constructor change and no rewiring.
    Measured on the same scenes:
    one row's elapsed time ticking 28 ms -> about 2 ms
    five rows plus a moving bar 11 ms total
    full-screen repaint 900 ms -> 140 ms
    Clocked at 24 MHz rather than the library's 32 MHz default. An ST7735S on
    jumper wires is not guaranteed at 32 MHz and the failure mode is cosmetic and
    confusing, speckles or a torn frame rather than a clean blank, so the margin
    is worth m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
    [beacon.ino]
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2026-09-04 Label sessions by repository, and recompute when the directory moves
    The display showed 'host' for a session in this repo. Two bugs behind it.
    The label came from the hook payload's cwd, which is the session's live
    working directory and moves as you work. Anything running in host/ relabelled
    the row. My own shell commands in this session caused exactly that.
    Worse, the label was only computed when the session was first seen, so once it
    was wrong it stayed wrong for the session's whole life, even after the
    directory moved back.
    The host now resolves cwd to the nearest ancestor holding a .git entry and
    uses that name, recomputing whenever cwd changes. Results are cached because
    hooks fire o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
    [main.py, state.py, test_state.py]
2026-09-04 Capture real hook payloads; the published schema was wrong in four places
    Closes the last open item from phase 1. The state machine was built against
    the published hook schema, never against a payload this machine actually
    sends, and the two disagree.
    Captured with the daemon itself rather than a second hook: no extra process
    per event, and it records exactly what the state machine sees. A headless
    'claude -p' run produced a full session lifecycle, which is the part an
    in-progress session cannot generate for itself.
    Field names this build actually sends, against what was published:
    session_start_reason -> source
    session_end_reason -> reason
    user_prompt -> prompt
    tool_ou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
    [capture.py, main.py, test_fixtures.py]
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2026-09-04 Say 'no statusline data' instead of leaving the footer blank
    The footer was empty because nothing feeds it. Cost and context reach the host
    only through the statusline hook, which install-hooks.ps1 leaves off by default
    so it cannot silently replace a status line someone already has. The result was
    a blank strip under the divider, which reads as a broken display rather than as
    a feature that was never switched on.
    The footer now says so. Entering or leaving that state repaints the whole
    strip, because the hint and the ctx/bar/model layout share no fields and
    drawing one over the other would leave fragments behind.
    Verified on hardware in both directions, including the transition back.
    Als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
    [beacon.ino]
2026-09-05 Mark the row the footer's context page describes
    The footer's context page reports one session's context window, and nothing on
    screen said which. With a single session that is unambiguous; with four it is a
    guess, and the natural guess is 'the one I was thinking about' rather than the
    correct 'whichever sorted to the top'.
    The featured row now carries a two-pixel marker down its left edge, in the gap
    before the state dot. It takes the label's colour, so it adapts to the state
    without another rule: white normally, black against the filled attention row,
    grey on an ended one.
    It stays put rather than appearing only while the context page is up. A marker
    blinking every four seconds would be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
    [beacon.ino]
2026-09-05 Correct the claim that env_monitoring's panel was RGB
    It was not. Its display shows high CO2 readings in blue instead of red, which
    is the same red/blue swap this project hit.
    The original claim was an inference presented as fact. env_monitoring's sketch
    defines COLOR_HEADER as 0x000F with the comment 'Dark blue', and I took the
    comment as evidence the panel rendered it that way. Nobody had looked at the
    screen. That inference then propagated into CLAUDE.md, hardware.md, the README
    and two sketch headers as 'colour order is a per-unit trait'.
    Both panels bought from this listing have been BGR, so expect BGR. Still check
    a new one, because the check is free: fill the screen with 0x000F and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
    [beacon.ino, tft_smoketest.ino]
2026-09-05 Add the enclosure: 3MF sources, BOM, and binary handling
    Three printed parts, fitted and working. Front, mid and back, each 40 x 60 mm,
    stacking to 19 mm, held by four M2 x 12 hex-head screws with nuts. Dimensions
    read from the mesh bounding boxes in the 3MF files rather than guessed.
    Records the full bill of materials, including one item that looks incidental
    and is not: 26 AWG hookup wire with soft insulation. Bring-up used breadboard
    jumpers, which are stiff enough to push the display off its seat and stop the
    case closing. Anyone rebuilding this from the wiring table alone would reach
    for jumpers and find the lid will not shut.
    Adds .gitattributes marking 3MF and other binaries. A 3MF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
    [back-v0.3MF, front-v0.3MF, mid-v0.3MF]
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2026-09-05 Prepare for public: MIT licence, generic examples, RP2040 invitation
    Adds LICENSE (MIT). Every dependency is permissive already: Adafruit GFX and
    pyserial are BSD, ArduinoJson, Adafruit BusIO and pytest are MIT. Nothing
    imposes copyleft, and MIT is the lowest-friction choice for the contributions
    this repo is now inviting.
    Replaces private project names used as sample data with generic ones. Those
    names were only ever placeholders, and a public repo has no business
    advertising what its author works on. The photo caption is the exception and
    keeps the real name, because it describes what is actually on the screen in
    the picture and inventing a caption for a photograph would be worse.
    Rebuil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
    [beacon.ino, test_state.py, tft_smoketest.ino]
2026-09-05 Add SolidWorks sources and STEP exports alongside the meshes
    Each part now ships in three formats, which are not redundant:
    .SLDPRT SolidWorks 2026 source, feature history intact
    .STEP neutral AP214 solid, opens anywhere, no history
    .3MF mesh, hand this to the slicer
    The STEP is what makes the project actually forkable. A dumb solid is still
    real geometry you can cut, extend and re-export; a mesh is not. Anyone
    adapting the case for a different board, which the README now explicitly
    invites, would otherwise be stuck remodelling from photographs or buying a
    SolidWorks licence. The RP2040 note points at it directly.
    784 KB for the whole directory, largest file 129 KB, so no LF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
    [back-v0.SLDPRT, back-v0.STEP, front-v0.SLDPRT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]
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2026-09-06 Fix a non-hermetic test, an over-counted context fallback, and lint
    Five issues from a fresh-clone review.
    The fixture test was not hermetic. It replayed a captured payload whose cwd is
    an absolute path from the machine that recorded it, and label resolution walks
    the filesystem for a .git. Anywhere else that path is absent, the walk finds
    nothing, and the label falls back to the basename "host". Confirmed by pointing
    the payload at a path that does not exist: it returns "host", so the old
    assertion would fail on any other machine. Split in two. The assertions that
    need no filesystem still run against the payload untouched; the label
    assertion rebuilds the repo shape under tmp_path and repo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
    [capture.py, config.py, hook_server.py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]
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2026-09-06 Add the 25-degree stand, and refresh the beacon photos
    The stand tilts the finished case back 25 degrees so the panel faces a seated
    viewer instead of the ceiling. It is one part, a single profile extruded 60 mm
    to match the case's long edge, and the body is a friction fit in the slot: no
    screws, no clips, and no feature on the case that it engages. That is why it is
    a separate object rather than a revision of `back` — it can be printed, skipped
    or replaced without touching a case that already fits.
    Print settings become a two-column table, clamshell against stand, and gain an
    infill row. Neither infill was chosen: the clamshell has only run at 20% and the
    stand at 15%, which is what the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
    [25-degree-stand-v0.3MF, 25-degree-stand-v0.SLDPRT, 25-degree-stand-v0.STEP]
2026-09-07 Let the attention alarm decay instead of pulsing forever
    A session waiting on a human pulsed red until something happened to it, and
    nothing in tick() ever retired that state. /health caught two sessions on this
    machine that had been pulsing for 13 hours and 9.7 hours. Leaving a session
    parked is the normal way to work, so the alarm was wrong far more often than it
    was right, and an alarm that is usually wrong stops being read.
    NEEDS_INPUT is now three rungs, timed from when the session entered the family:
    `need` pulses for two minutes, `held` holds the same filled red without moving
    for eight more, and `wait` is an ordinary row with an amber dot.
    Three parts of this are load-bearing and e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
    [beacon.ino, config.py, main.py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]
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2026-09-07 Survive a restart, and stop a second daemon sharing the port
    Two faults with one symptom: the display quietly showing fewer sessions than
    are open, which the troubleshooting guide blames on missing hooks.
    Session state lived only in memory, and a session parked on a prompt sends no
    hook events at all, so there was nothing to re-register it. Every restart -- at
    logon, after a crash, or to free the COM port for a reflash -- dropped every
    waiting session until each one was next touched. Found by restarting the daemon
    to flash firmware and watching two waiting sessions vanish.
    The store is now written to sessions.json beside the log whenever the snapshot
    changes, throttled to five seconds, and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
    [config.py, hook_server.py, main.py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]
2026-09-07 Stop treating a turn that ends on background work as idle
    A turn that ends while a subagent is still running fires Stop, so the session
    went IDLE, and the next idle_prompt escalated it to a pulsing red row with
    nothing for anyone to do. Reported from the desk: the beacon went red while the
    session was only waiting for agents.
    Stop carries background_tasks. The empty list had been in the fixtures since the
    first capture, which showed the field existed but not what an entry looks like,
    so this waited for a real payload rather than guessing:
    "background_tasks": [{"id": "...", "type": "subagent",
    "agent_type": "Explore", "status": "running",
    "d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
    [capture.py, state.py, test_fixtures.py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]
2026-09-07 Make protocol.md describe the firmware that exists
    Six claims in the wire contract were wrong, found by auditing the doc against
    the sketch. The protocol doc is the one place a second implementation would be
    written from, so drift here is worse than elsewhere.
    The heartbeat is every 3 s, not 10, and carries nine fields rather than three:
    rx, bad, drop, since, render and spi were undocumented, though they are the
    whole reason the heartbeat is interesting. A quiet host and a device dropping
    lines look identical from outside, and those counters tell them apart.
    "Host uses its absence to detect a wedged device" was never implemented. The
    lines are drained and debug-logged. Recorded as such, an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
    [beacon.ino]
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2026-09-07 Capture the idle_prompt notification the red row rests on
    The attention state was the one part of the display resting on inference. The
    README said so plainly: the events that drive a red row had never been seen
    firing, so "leaving a session on a prompt turns its row red" was reasoning about
    a state machine rather than a thing observed.
    The capture taken for the background_tasks fix kept running afterwards and
    recorded two of them. `Notification` with `notification_type: "idle_prompt"`,
    carrying a `message`, which is the path an ordinary session takes when it
    finishes a turn and nobody answers. Committed as a fixture, so the red row is
    now covered by a replayed payload rather than a hand-wr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
    [state.py, test_fixtures.py]
2026-09-07 Capture the permission prompt, and stop it leaking the command line
    The last unobserved event on the attention path. Triggered by switching a
    session to manual approval and running a command that needs one, with the daemon
    capturing, so the red row now rests entirely on replayed payloads.
    PermissionRequest carries tool_name, a redacted tool_input, permission_mode, and
    an undocumented permission_suggestions: the rule Claude Code offers to add if
    you pick "allow always". That last field needed a capture change before the
    payload could be committed. Its ruleContent is built from the command line, so
    it echoes the text that redacting tool_input exists to strip -- "python -c ' *"
    in the one capt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
    [capture.py, state.py, test_fixtures.py]
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2026-09-11 Show an orchestrator waiting on a workflow as cyan, not red
    An orchestrator session waiting on a background `workflow` task went
    filled red and pulsing, the treatment a permission prompt gets, with
    nothing blocked. Only `subagent` is counted as work in flight, so its
    Stop read as "nothing running", the row went IDLE, and the next
    idle_prompt skipped the hold and took the full alarm.
    Widening that count is the monitor bug again, so it stays subagent-only.
    What was wrong is that the ladder had one severity for two messages: a
    permission prompt means "I cannot go on without you", an idle_prompt
    only "the main thread has been quiet a while". A second count,
    `bg_other`, now holds live background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
    [beacon.ino, config.py, main.py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]
2026-09-11 Drop sessions killed by a reboot instead of showing them for days
    A row sat on the display for 45 hours after its session was gone. A
    Windows Update restart at 20:37 killed a nanovolt-divider session without
    a SessionEnd, and the daemon, starting at logon ten minutes later,
    restored it from sessions.json as though it were parked. The next daemon
    restart found it 21 hours old, under the 24-hour cutoff, and restored it
    again. Nothing removes a session from the running store short of
    SessionEnd, so it stayed until a restart finally caught it past the
    cutoff.
    Two holes, both closed. persist.load() now restores nothing if the
    machine booted after the file was saved: no Claude Code process surviv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
    [config.py, main.py, persist.py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]
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2026-09-17 Reboot the board out of a dead serial return path
    "beacon stuck: replug" was shown for over two hours against a beacon whose
    rows were visibly ageing. Only the return path was dead. Every outgoing
    line passes hostAttached(); inbound data passes nothing, so a false flag
    silences the board completely and costs it nothing else.
    That flag is tud_mounted() && !tud_suspended() && DTR, three facts that can
    each go false without the pipe stopping. Dropping the checks in txLine()
    and txPump() looks like the fix and is not: USBCDC::write() and
    availableForWrite() test the same flag themselves and return 0 while it is
    false, so no byte can leave by any route the sketch controls. Nor can the
    host cure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
    [beacon.ino, serial_link.py, statusline.py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]
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2026-09-18 Restart the daemon through one script, and make an orphaned one visible
    A daemon started with Start-Process after a firmware flash was invisible to
    the Scheduled Task: Stop-ScheduledTask had nothing to stop and the task's
    fresh copy died on the port bind, with only a non-resetting uptime to show
    for it. scripts/restart-daemon.ps1 now kills every beacon-host process
    however it was started, starts the task, and fails unless a fresh daemon
    answers /health; -StopOnly frees the ports for flashing. /health reports
    the daemon's pid, and a lost bind logs the PID holding the port.
    Task lookups move to schtasks.exe. Get-ScheduledTask fails for every task
    when any one on the machine is malformed, and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
    [hook_server.py, main.py, test_daemon.py]
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
